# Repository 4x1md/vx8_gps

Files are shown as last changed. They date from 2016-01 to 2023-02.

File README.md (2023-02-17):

# DIY GPS Module for Yaesu VX-8DR/VX-8DE Handheld Transceiver
GPS module for Yaesu VX-8DR/DE handheld transceivers with ublox NEO-6M chip and Arduino Nano by Dmitry Melnichansky 4Z7DTF (~~4X5DM since June 2016~~ 4X1MD since July 24, 2017).

## Overview

When I was buying my Yaesu VX-8DE, I knew that I wasn't going to buy the original Yaesu FGPS2 module. There is very little APRS coverage in Israel and APRS in general seemed quite useless to me. The unreasonably high price of the original module didn't make me want to try it either.

After receiving far APRS stations during a strong tropo over the Mediterranean I thought it would be nice to transmit some data. I started investigating how GPS transmits data and discovered the NMEA protocol I had never encountered before. My first source of information was the article [Reverse Engineering the Yaesu VX-8DR GPS Interface](http://lingnik.com/2013/02/09/reverse-engineering-yaesu-vx-8dr-gps-interface.html) by Taylor J Meek KG7BBG.

I started from writing a Python program which was sending NMEA sentences to the transceiver. After some research I discovered the required message format and wrote a program which drew flowers on APRS map.

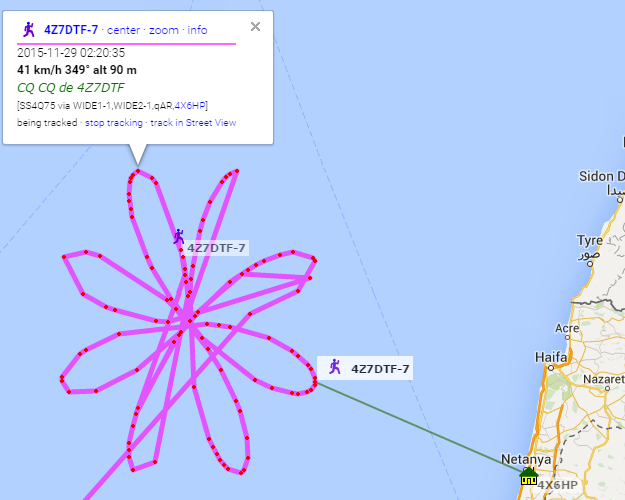
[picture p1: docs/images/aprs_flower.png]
APRS flower


Later, [David Fannin's project](https://github.com/dfannin/arduino-vx8r-gps) inspired me to build my own GPS module. Thanks to his project I found out the ublox NEO-6M chip and a simple search on AliExpress showed that a ready module can be puchased for $10-20.

I wrote my own software which isn't based on David Fannin's code. I started it as Arduino project but after finding out that the standard Arduino Serial library doesn't support interrupt driven writing and reading I decided to write it in pure C. After small changes the C code can be compiled in Arduino environment. The Arduino code is located in [/arduino/vx8_gps_16mhz folder](https://github.com/4x5dm/vx8_gps/blob/master/arduino/vx8_gps_16mhz) of this repository.

I tried to document this project as much as possible and I hope it will be interesting and useful for other radio amateurs.

## Yaesu VX-8DR/DE and NMEA protocol
The NMEA protocol is implemented in the VX-8 in a non-standard way. There are two main issues with it: serial port parameters and NMEA sentence format. There is also a data validation issue which is very interesting but less important in this case.

### Port parameters: baud rate and logic levels
The original Yaesu FGPS2 module transmits at 9600 bps instead of the standard 4800 bps and uses 3.3V logic level instead of the standard 5V. This isn't a big issue because there are GPS modules which can be configured to transmit at 9600 bps and logic levels can be converted. The GY-GPS6MV2 module came already pre-configured to 9600 bps rate. The ublox NEO-6M chip used in this module has maximum supply voltage of 3.6V. As we see there are no electrical compatibility issues at all.
### NMEA sentence format: field lengths
VX-8 requires all the fields of the NMEA sentence to be padded to the maximum possible number of symbols while regular NMEA standart allows fields to be empty. It means that if there is no GPS fix, typical GGA message will have the following form:
```
$GPGGA,074222.000,,,,,0,00,99.9,,,,,,0000*6E
```
The radio won't be able to process this message and we'll see gibberish on the display. A correct sentence for this transceiver should have the following format:
```
$GPGGA,200124.000,0000.0000,N,00000.0000,E,0,00,00.0,00000.0,M,0000.0,M,000.0,0000*46
```
Sending a sentence with empty fields will result in gibberish on the GPS screen of VX-8. Here is what we'll get.

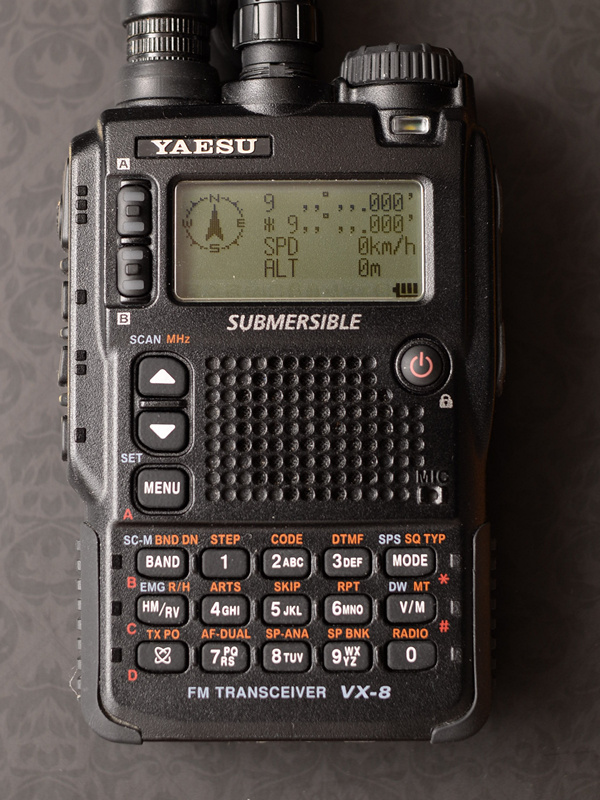
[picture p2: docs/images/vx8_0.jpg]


Allthough the sentence accords with the standard, the transceiver isn't able to process it correctly.

Actually setting number of sybols in each field is what all this project is about! If the second issue didn't exist we could connect the ublox NEO-6M chip based module directly to the transceiver.

### NMEA data validation
Here the things get even more interesting. Yaesu VX-8 does no validation on the NMEA data. When I say no validation, I mean **no validation at all**! Let's look at the following NMEA sentence.
```
$GPGGA,999999.000,73DE.0000,!,Z7DTF.NOPQ,4,1,04
```
The time in the first field is invalid, the latitude and longitude fields have letters instead of numbers, the North/South and East/West fields have invalid characters as well. The checksum is missing. Should it be thrown away by the receiving device? Yes, sure! But let's see how VX-8 will respond!

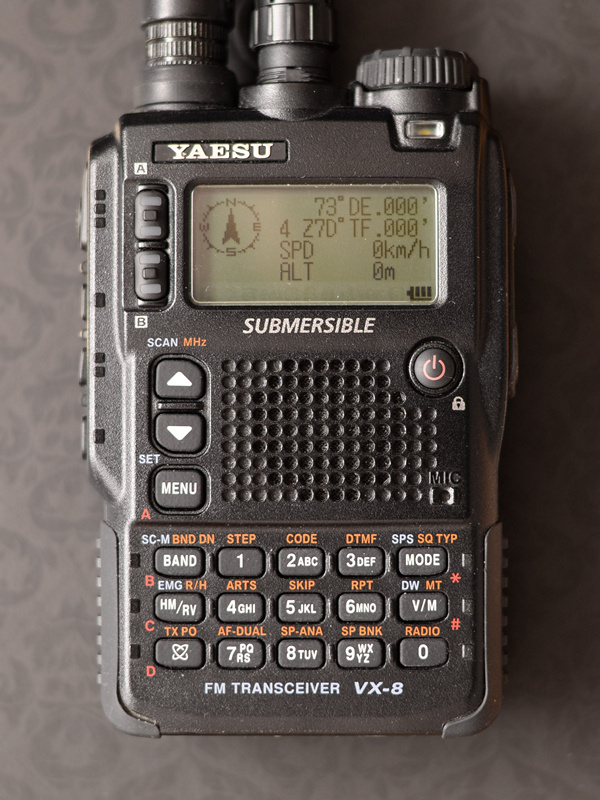
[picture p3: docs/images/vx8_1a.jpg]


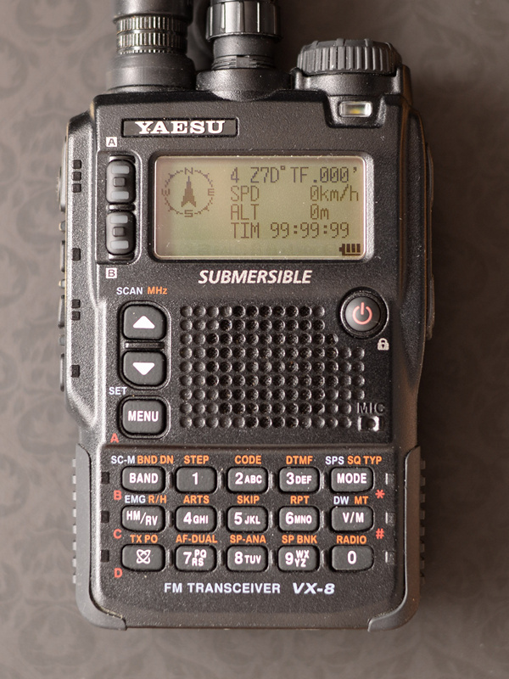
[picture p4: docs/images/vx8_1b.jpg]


Have you ever thought about writing some text on the display of your VX-8? Or maybe about setting the time to 89:91:75? Now you know how to do it!

Let's try one more example where there will be no numbers in latitude and longitude fields.
```
$GPGGA,999999.000,ello.ABCD,H,itHub.ABCD,G,1,04
```
And the output is:

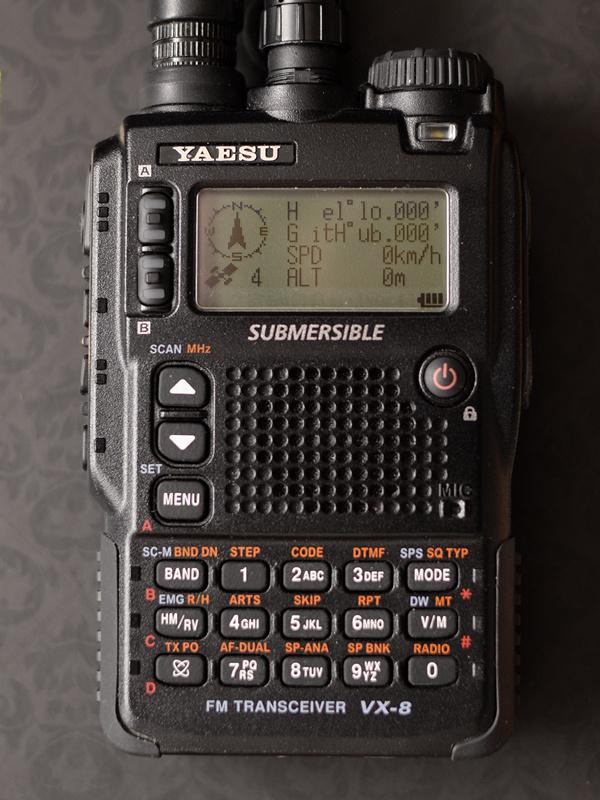
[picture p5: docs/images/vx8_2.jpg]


Note that last two fields of our so called NMEA sentence mean that there was a valid GPS fix and that it was acquired from 4 satellites. This is exactly what we see on the display: satellites icon with number 4 under it.  This is enough for the transceiver to enable APRS beacon transmission. If you press the internet (TX PO) key these coordinates will be transmitted. Obviously, APRS site will mark such packet as invalid.

When I told you that there is no data validation I really meant no validation at all! You don't even have to add checksum as it will be completely ignored by the radio.

If you want to try it your self you'll need a standard programming cable (original or one from AliExpress) and a terminal program. I used [PuTTY](http://www.putty.org/). Open a new session, choose the correct serial port, set it to 9600 8N1 and you are ready to go. Right mouse click in the terminal window pastes the message from the clipboard. After pasting your message press CTRL+M and then CTRL+J. It will send the CR and LF (ASCII 13 and 10) symbols which mark the end of NMEA sentence.

## Hardware

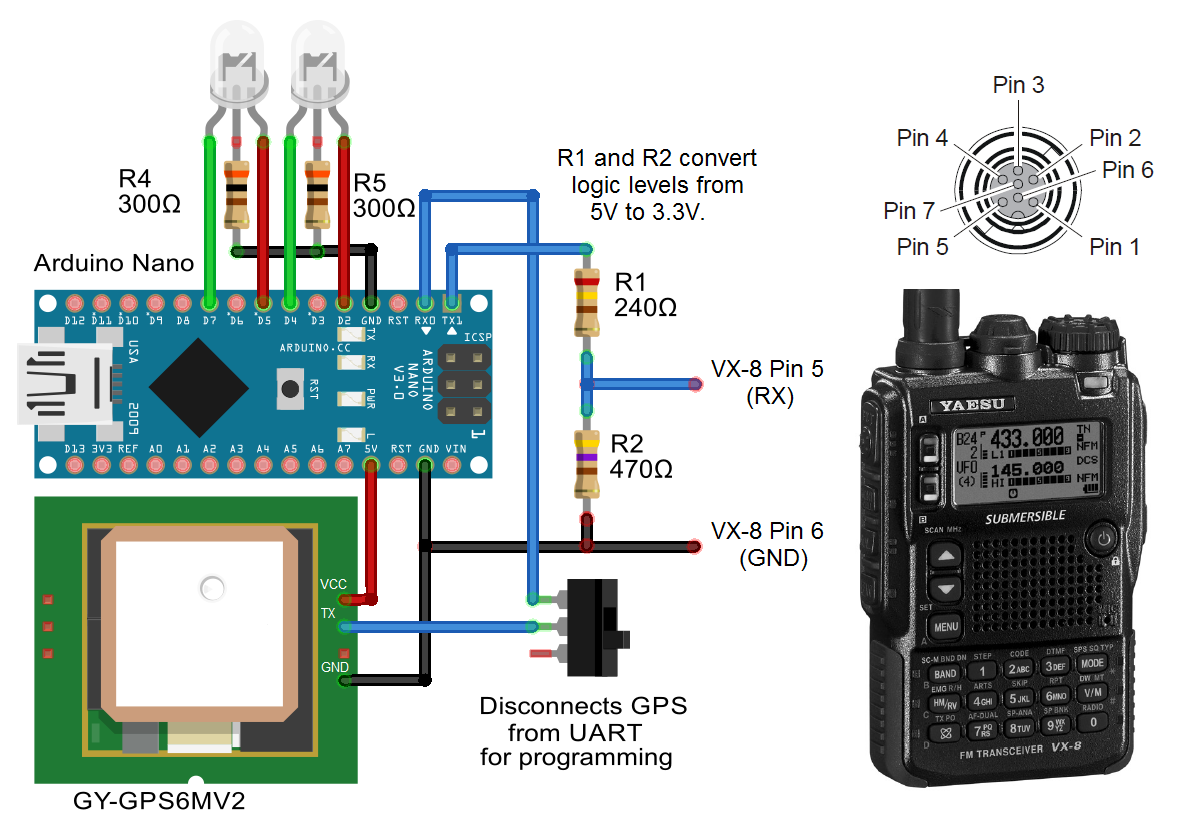
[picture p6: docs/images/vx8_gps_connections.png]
Schematic


The hardware is quite simple. GY-GPS6MV2 GPS module transmits its data to the Arduino which does necessary processing and sends it to the transceiver. Allthough the communication between the original Yaesu FGPS2 module and the radio is bi-directional, in my project I decided to make it unidirectional from GPS to radio. Not only is the bi-directional communication useless in this case but also requires one more serial port. This configuration uses only one serial port to communicate with both devices.

Important! The serial port on the Arduino board is also used for programming the device. Leaving the GPS connected to the serial RX pin will cause a conflict and make uploading the firmware impossible. That's why there is a switch which disconnects GPS output from serial input.

On the contrary, using USB serial when the transceiver is connected not only is possible but also is recommended for debugging purposes. You can use any terminal program to monitor Arduino's output even when the radio is connected.

Voltage divider formed by 240 Ohm and 470 Ohm resistors converts the logic levels from 5V used by Arduino to 3.3V required by the transceiver. Two two-color LEDs are used for indication. The left one blinks red if a GGA message was rejected and green if it was sent to the radio. The right one does the same for RMC messages.

All the setup is very similar to [David Fannin's GPS project](https://github.com/dfannin/arduino-vx8r-gps). Main difference is that his project implements bi-directional communication using software serial port emulation for the second port.

The GY-GPS6MV2 GPS recevier and the Arduino Nano clone were both purchases on AliExpress for less than $15.

## Software

To be completed...

## Development history

### First protoype: Arduino Nano and u-blox NEO-6M

The first version was built with readily available modules on a prototype PCB.

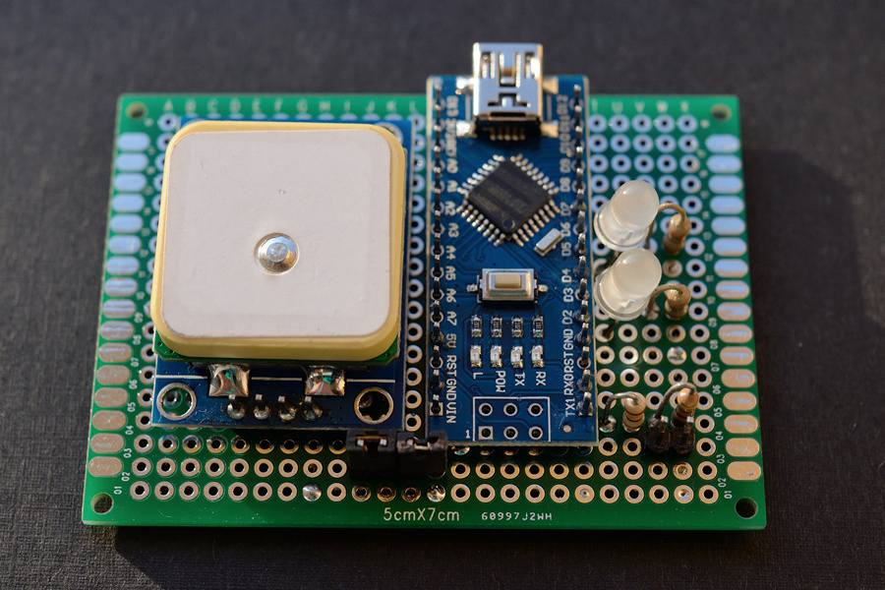
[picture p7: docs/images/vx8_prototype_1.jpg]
Prototype


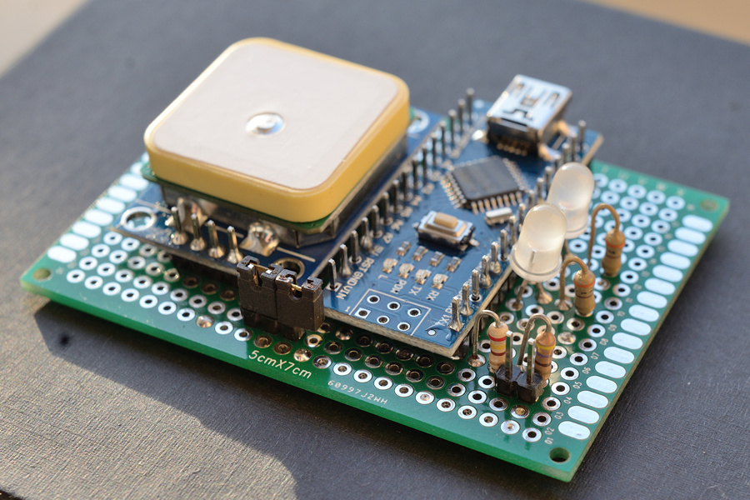
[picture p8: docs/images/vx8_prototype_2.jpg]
Prototype


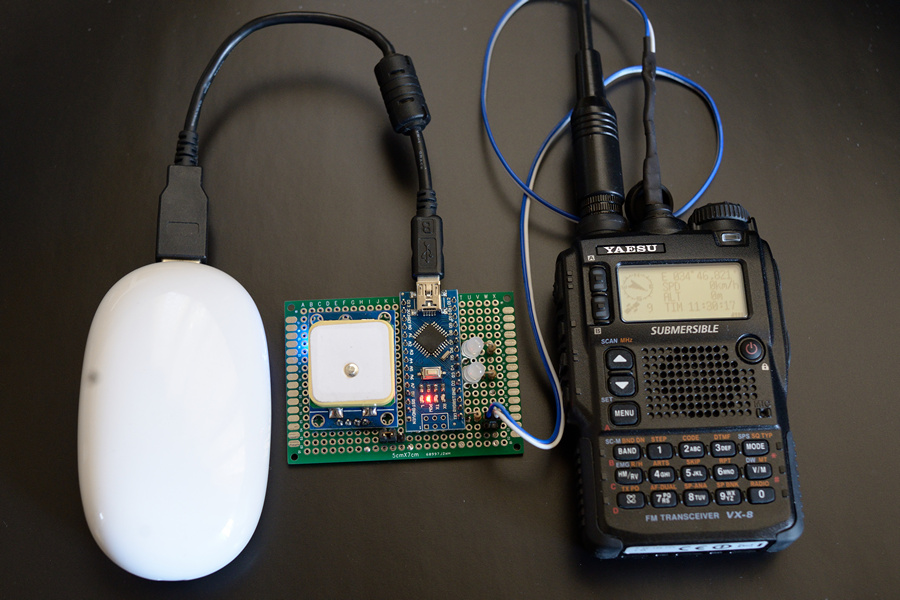
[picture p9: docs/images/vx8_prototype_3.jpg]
Prototype


### PCB v1.0

The first prototype was built on a dedicated PCB with a standalone ATmega328P-20PU microcontroller in 28 pin DIP package. The PCB was produced at home.

Refer to [prototype_v1.0.md](https://github.com/4x5dm/vx8_gps/blob/master/docs/prototype_v1.0.md) for details.

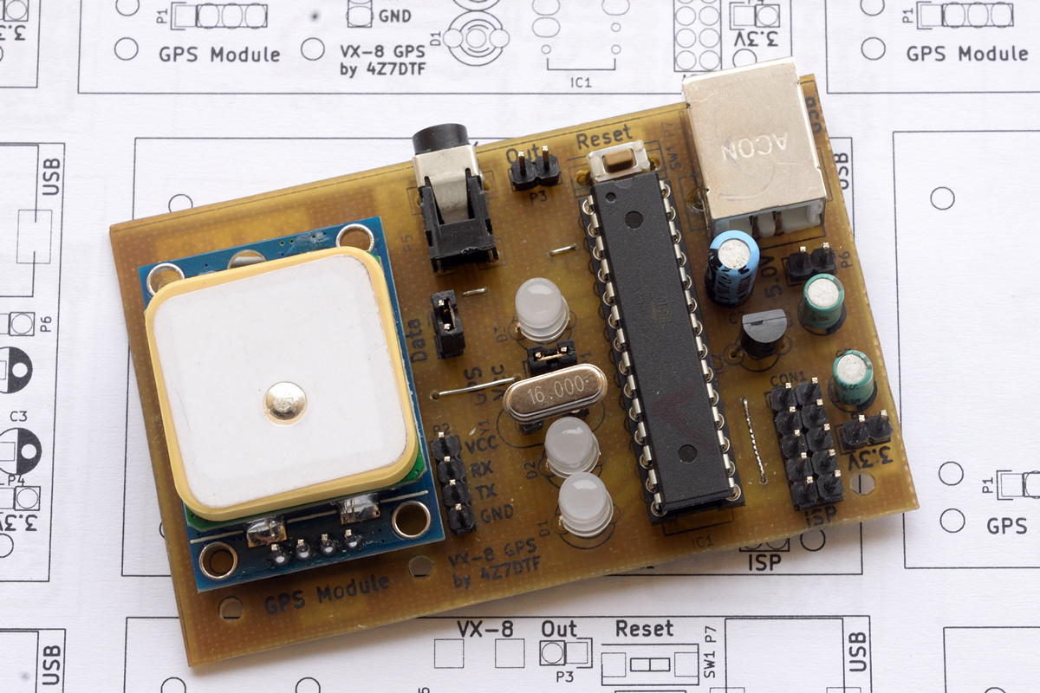
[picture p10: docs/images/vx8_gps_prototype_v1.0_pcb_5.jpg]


### PCB v2.0

This version has a USB-to-UART IC which allows the GPS to be used as a programming cable. It was designed as a two-side PCB with SMD parts. Allthough I developed the schematics and the PCB, this version was never built.

The circuit diagram of this version can be found [here](https://raw.githubusercontent.com/4x5dm/vx8_gps/master/docs/images/vx8_gps_prototype_v2.0_schematic.png). Design files are located [here](https://github.com/4x1md/vx8_gps/tree/master/pcbs/vx8_gps_prototype_v2.0).

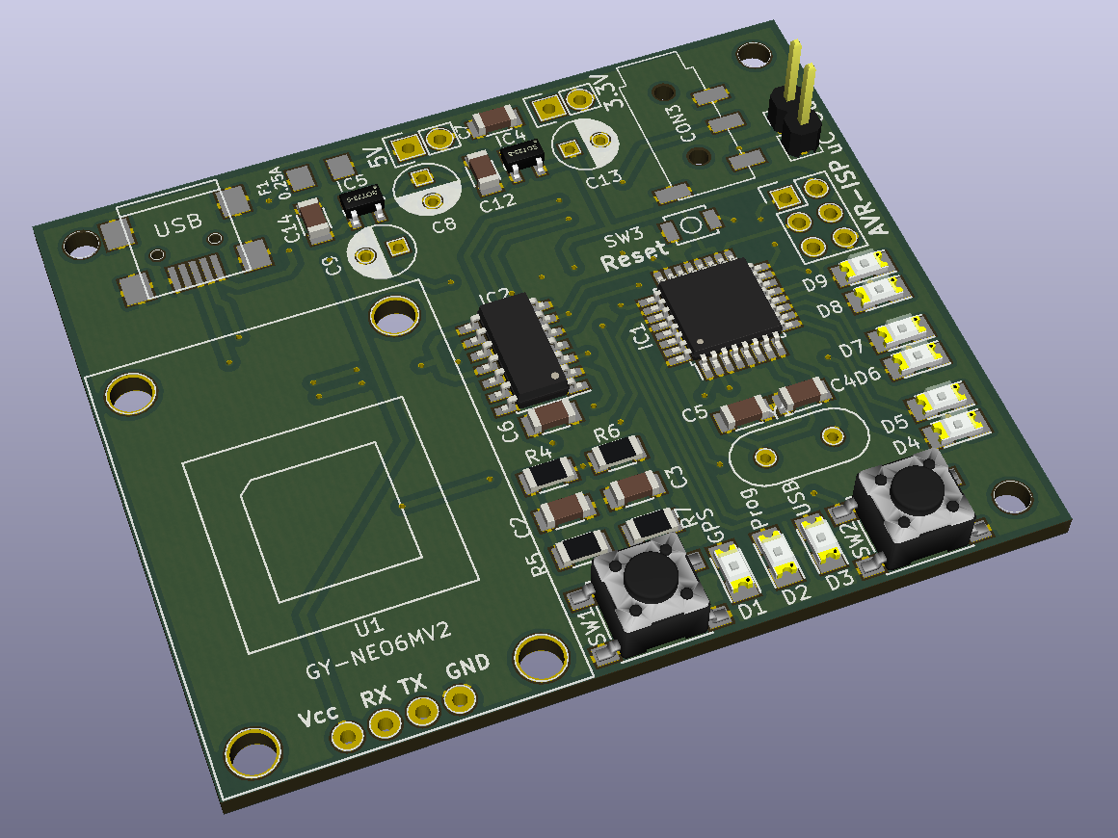
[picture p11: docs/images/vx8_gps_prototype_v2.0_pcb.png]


### PCB v3.0

This version was built on a two-layer PCB. Most parts including ATmega328P microcontroller and the GPS module are SMD. The size of this PCB is 43.5x43.5mm and it was designed to fit a small plastic enclosure box.

Refer to [prototype_v3.0.md](https://github.com/4x5dm/vx8_gps/blob/master/docs/prototype_v3.0.md) for details.

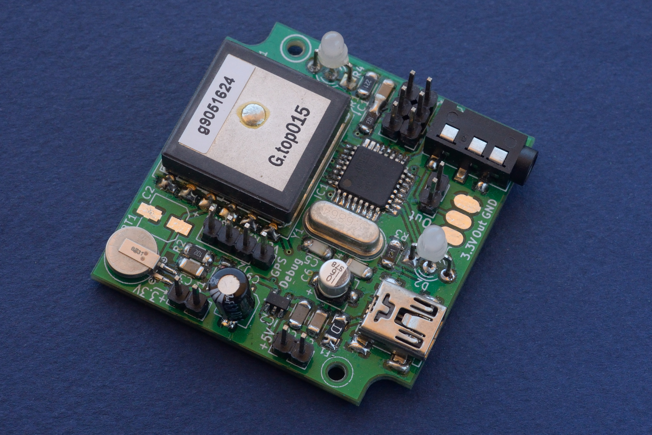
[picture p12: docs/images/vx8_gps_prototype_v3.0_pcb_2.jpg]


## Field tests

The unit was tested in trains. Videos from the tests are available.

1. [Test 1: Herzliya station](http://www.youtube.com/watch?v=POHEborbWdw)
2. [Test 2: Kiryat Gat station](https://www.youtube.com/watch?v=_s_EKdAwrpI)

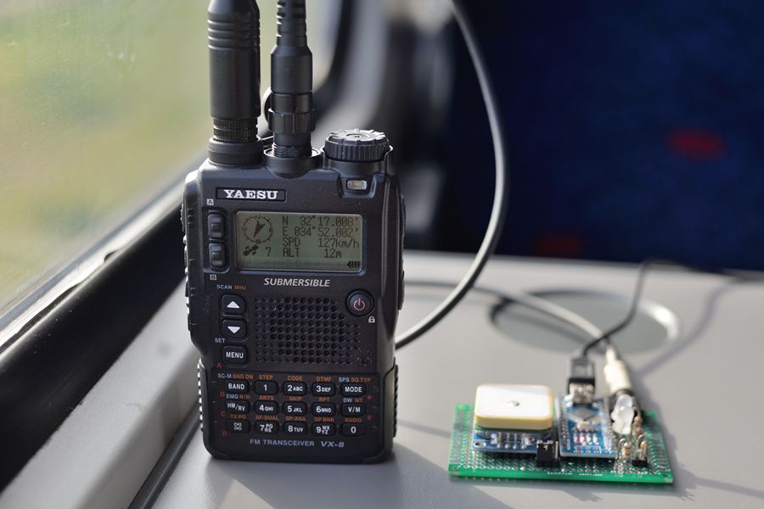
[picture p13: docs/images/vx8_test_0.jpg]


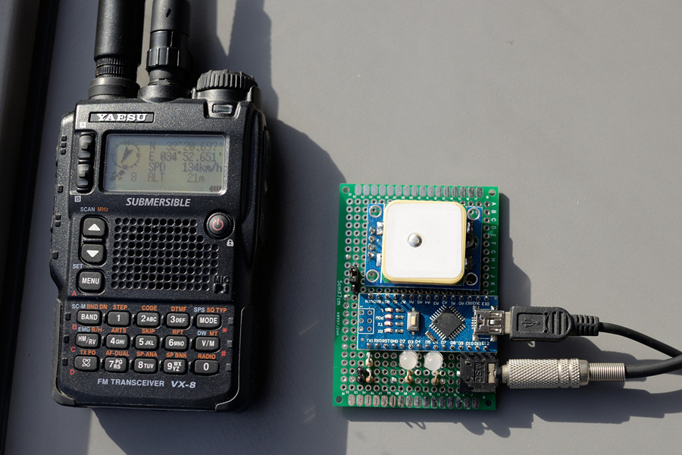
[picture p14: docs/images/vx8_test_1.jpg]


## Plans for future development

1. [x] ~~Running all the system at 3.3V.~~ See [prototype_v1.0.md](https://github.com/4x5dm/vx8_gps/blob/master/docs/prototype_v1.0.md) for details.
2. [x] ~~Reducing the microcontroller speed to 8MHz or even lower.~~ See [Release v1.0](https://github.com/4x5dm/vx8_gps/releases/tag/v1.0) ([commit 9e8273a](https://github.com/4x5dm/vx8_gps/commit/9e8273abed9b53197791b6e432649a282e6ca909)) .
3. [ ] Adding a rechargeable battery and making the device USB chargeable.
4. [x] ~~Building the project on a PCB instead of using ready modules.~~
5. [x] ~~Assembling the device in one enclosure box.~~
6. [ ] Making the module compatible with Nikon DSLRs.

Optional/questionable features:

1. [ ] USB serial chip to use the device as a programming cable.
2. [ ] microSD card slot and keeping logs of the tracks.
3. [ ] LCD display for displaying current GPS data.

## Links
1. [Reverse Engineering the Yaesu VX-8DR GPS Interface](http://lingnik.com/2013/02/09/reverse-engineering-yaesu-vx-8dr-gps-interface.html)
2. [FGPS2 data samples (VX-8R Yahoo Group)](https://groups.yahoo.com/neo/groups/VX_8R/conversations/topics/7719)
3. [David Fannin's Yaesu VX-8R Handheld Transmitter-compatible GPS](https://github.com/dfannin/arduino-vx8r-gps)
4. [NMEA to Yaesu VX-8 by G7UHN](http://alloutput.com/amateur-radio/nmea-to-yaesu-vx-8/)
5. [VX-8DR and GPS by VK3YY](https://vk3yy.wordpress.com/2015/07/24/vx-8dr-and-gps/)
6. [GPS - NMEA sentence information](http://aprs.gids.nl/nmea/)
7. [MTK NMEA checksum calculator](http://www.hhhh.org/wiml/proj/nmeaxor.html)
8. [avr-libc 2.0.0: <avr/interrupt.h>: Interrupts](http://www.nongnu.org/avr-libc/user-manual/group__avr__interrupts.html)

## Questions? Suggestions?
You are more than welcome to contact me with any questions, suggestions or propositions regarding this project. You can:

1. Visit [my QRZ.COM page](https://www.qrz.com/db/4X5DM)
2. Visit [my Facebook profile](https://www.facebook.com/Dima.Meln)
3. Write me an email to iosaaris =at= gmail dot com

## How to Support or Say Thanks

If you like this project, or found here some useful information and want to say thanks, or encourage me to do more, you can buy me a coffee!



"Buy Me A Coffee" (https://www.buymeacoffee.com/4x1md)

You can aslo make a donation with PayPal:



---

**73 de 4X1MD ex 4X5DM ex 4Z7DTF**

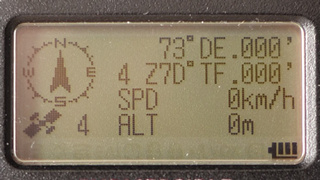
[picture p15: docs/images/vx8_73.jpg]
73's


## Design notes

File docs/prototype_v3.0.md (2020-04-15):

# DIY GPS module for Yaesu VX-8DR/VX-8DE Version 3.0

## Overview

This version of the GPS was developed in order to reduce its size and to assemble it in a small plastic enclosure. It is built on a two-layer PCB.

Both schematics and the PCB were developed in KiCAD software. Source files are available in [pcbs/vx8_gps_prototype_v3.0](https://github.com/4x1md/vx8_gps/blob/master/pcbs/vx8_gps_prototype_v3.0) of this repository.

## Schematics

This version uses a G.top015 surface-mounted GPS module based on MTK3333 chipset. It supports both GPS and GLONASS. The module transmits GPS data at 9600 bps. It is very simple to use and doesn't require any software configuration. It uses 3.3V logic levels which match those required by VX-8DR. In order to keep the internal RTC running when the main power is turned off, an external battery can be used. Without it the module will perform a lengthy cold start every time it is powered-on because previous satellite information is not retained and needs to be reacquired. MS621FE backup battery is used in this project.

The microcontroller is ATmega328P like in the previous versions. This version uses the TQFP-32 package.

The circuit is powered from an external 5V source. The power is supplied through a Micro-USB connector. It makes possible to power the GPS from a portable power bank with a USB port. The GPS module and the microcontroller need 3.3V to function. This voltage is supplied by MIC5205-3.3BM5 fixed output linear regulator.

All the passive parts are 1206 SMD for easy soldering. The only through-hole parts are crystal, LEDs and terminal headers.

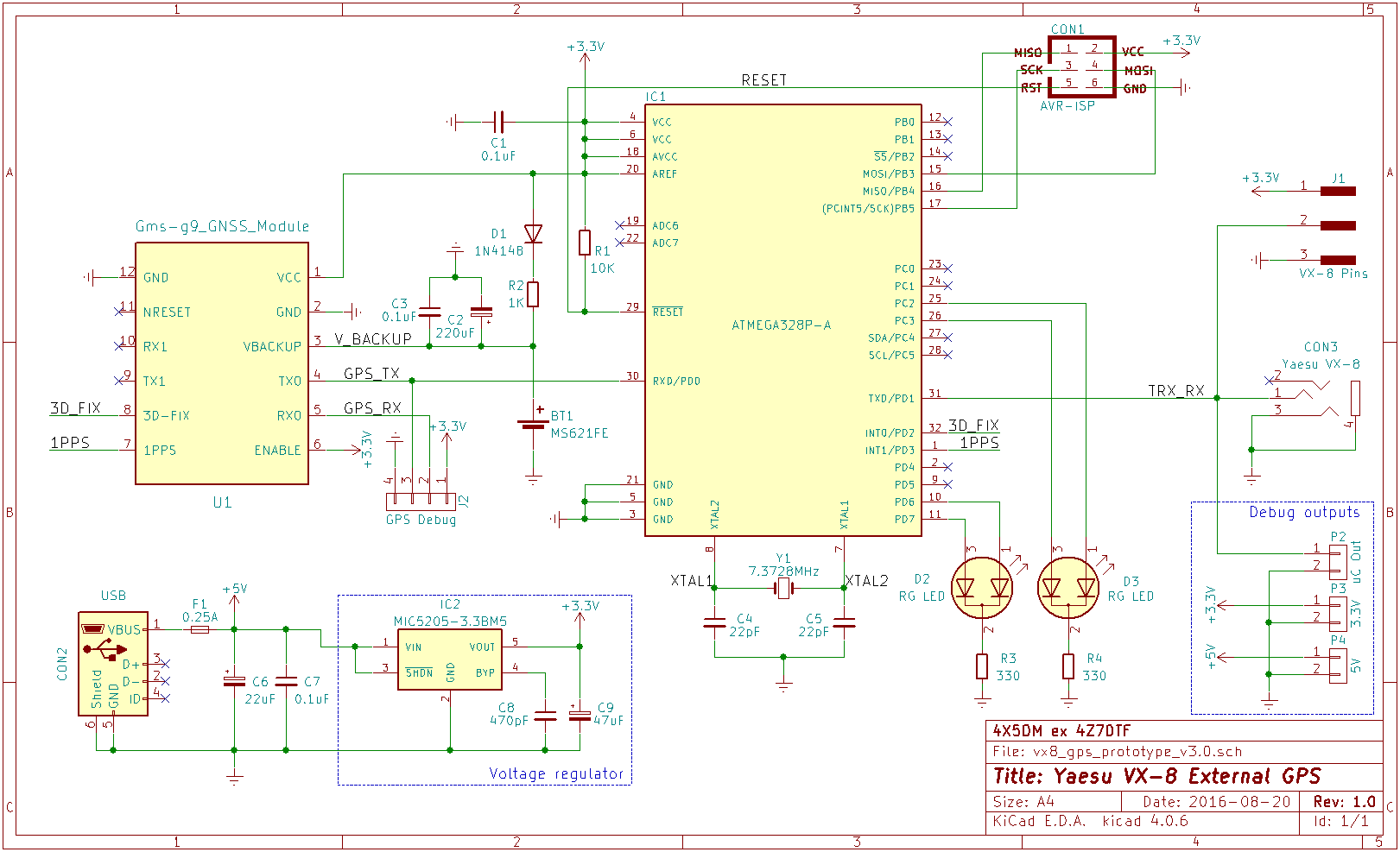
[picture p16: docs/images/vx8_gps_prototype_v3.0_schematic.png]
Schematic


## Mechanics

One of the requirements of this GPS version was an enclosure box. I chose 51x51x15mm plastic box which is small, strong and can be bought cheap on eBay and AliExpress.

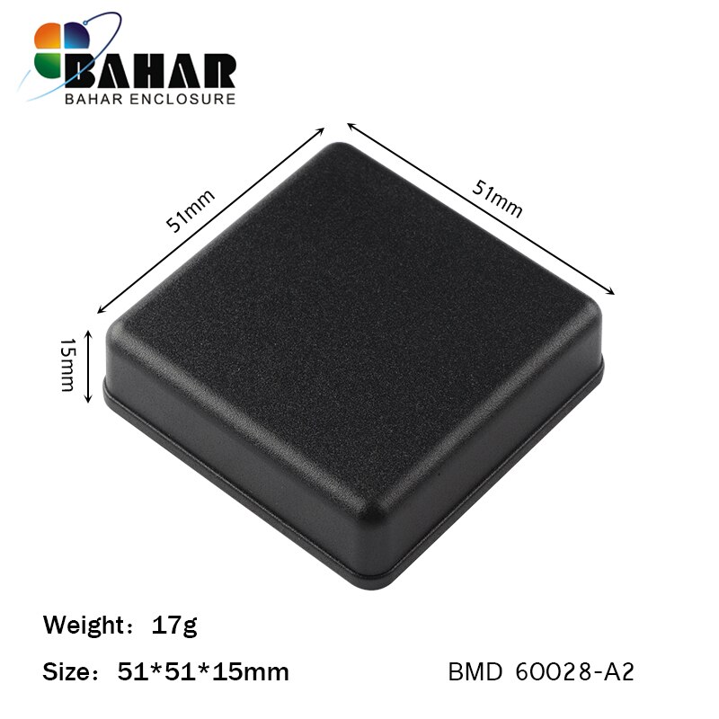
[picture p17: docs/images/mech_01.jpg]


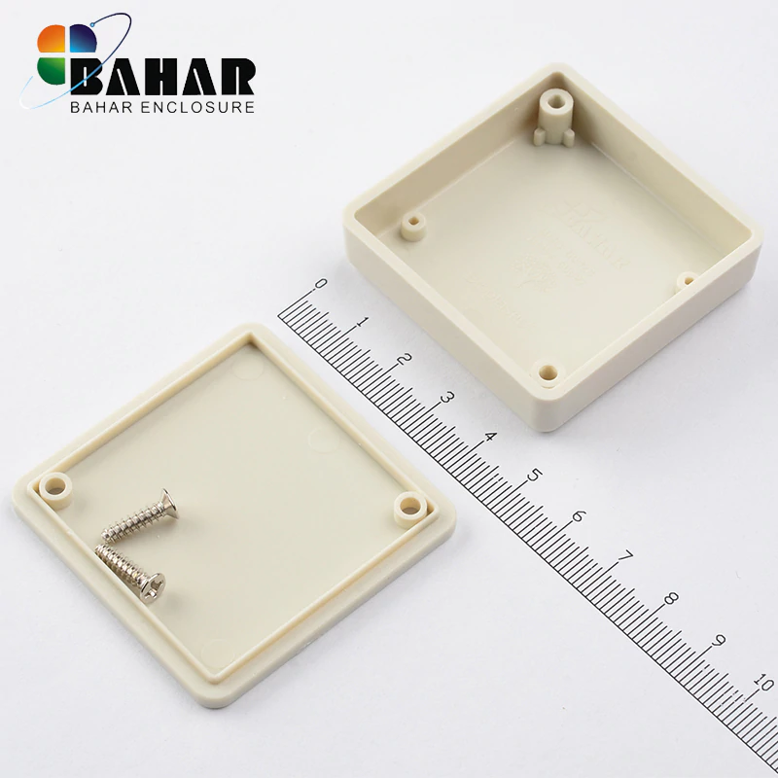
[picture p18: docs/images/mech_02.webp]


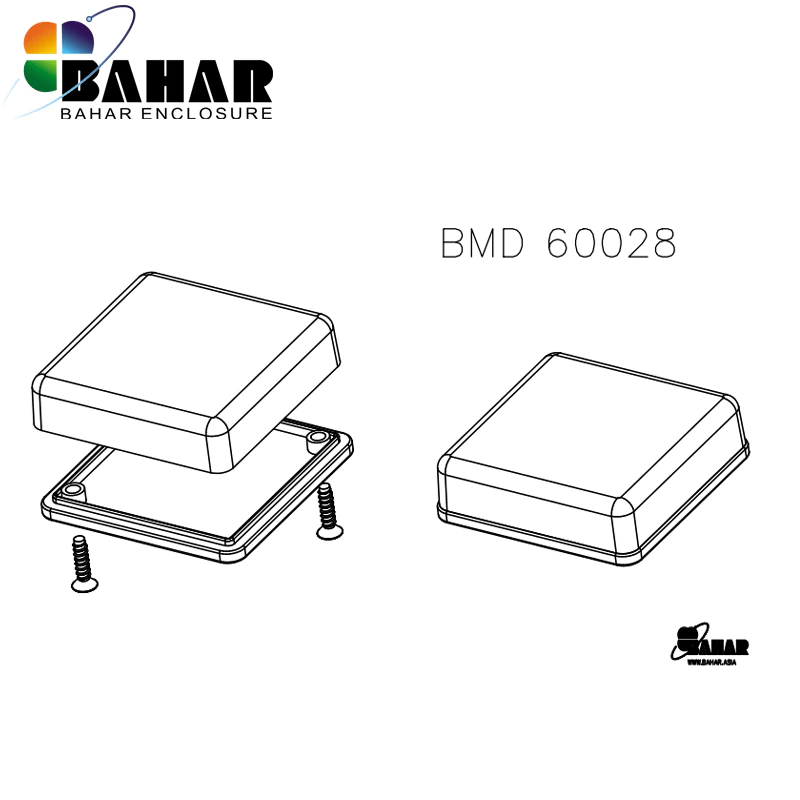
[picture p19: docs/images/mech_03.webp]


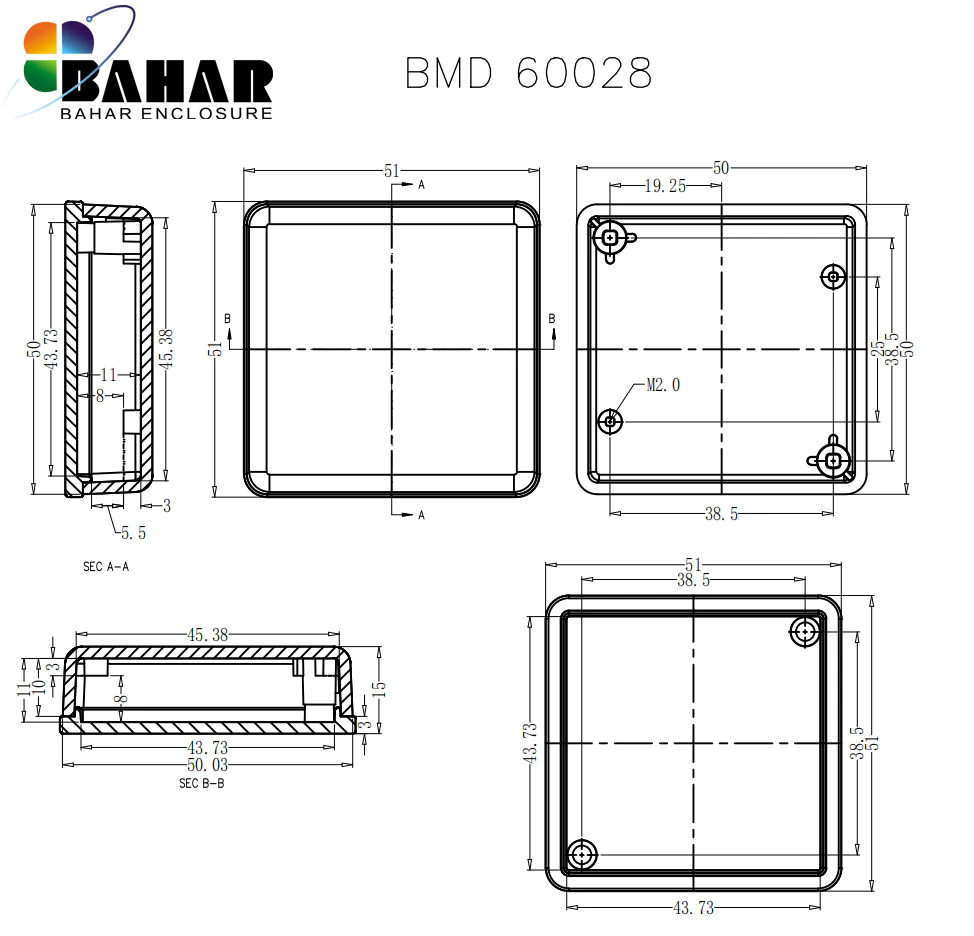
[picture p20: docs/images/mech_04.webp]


## PCB

The PCB is a two-layer board. Its size is 43.5x43.5mm based on manual measurement of the enclosure box.

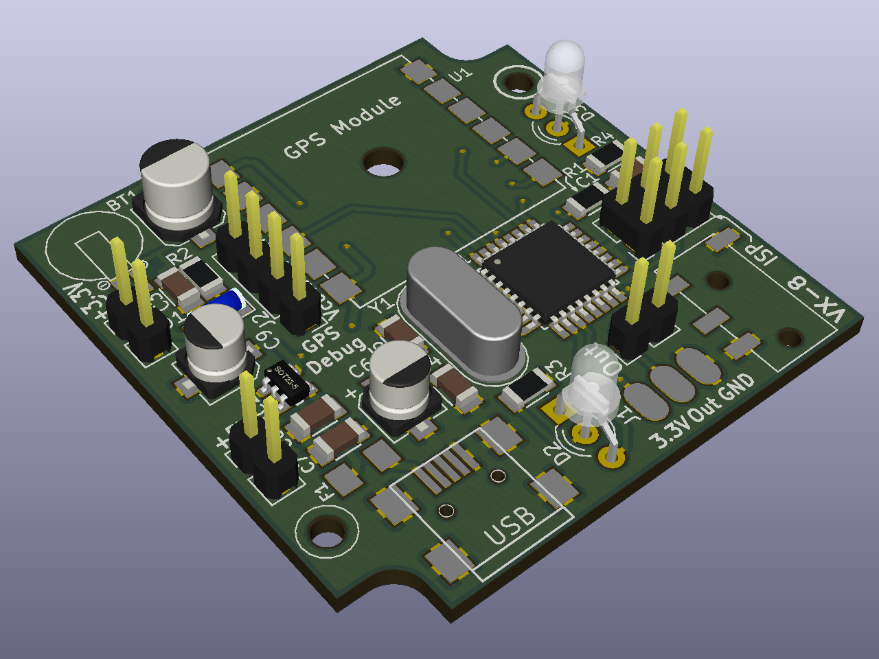
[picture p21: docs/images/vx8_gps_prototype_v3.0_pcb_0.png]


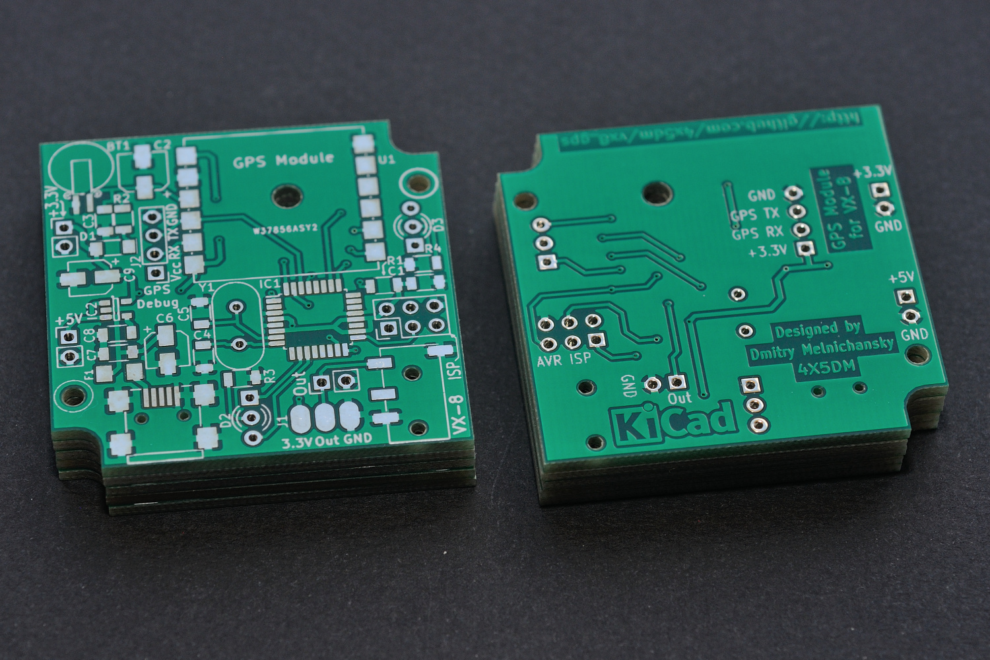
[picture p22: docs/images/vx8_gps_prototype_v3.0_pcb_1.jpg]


## Photos

PCB

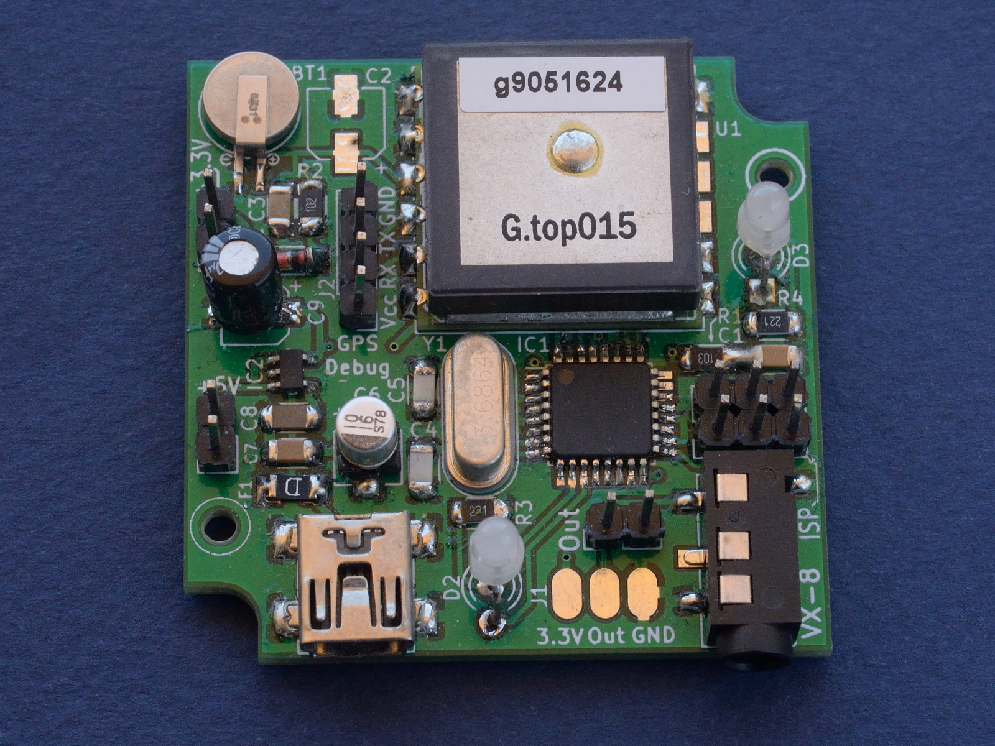
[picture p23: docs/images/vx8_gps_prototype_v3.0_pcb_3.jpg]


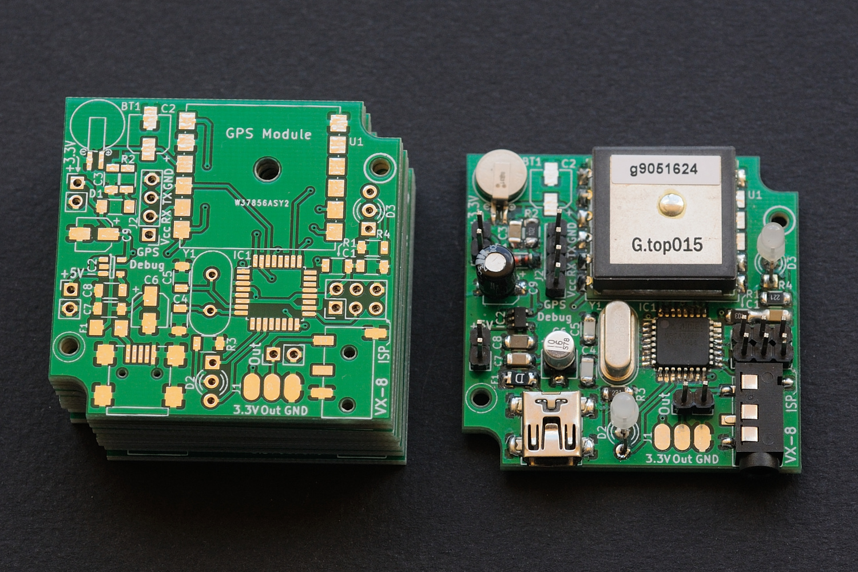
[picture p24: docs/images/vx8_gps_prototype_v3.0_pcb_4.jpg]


## Field Tests

The new module was tested in Israel and abroad and I'm satisficed with its performance.

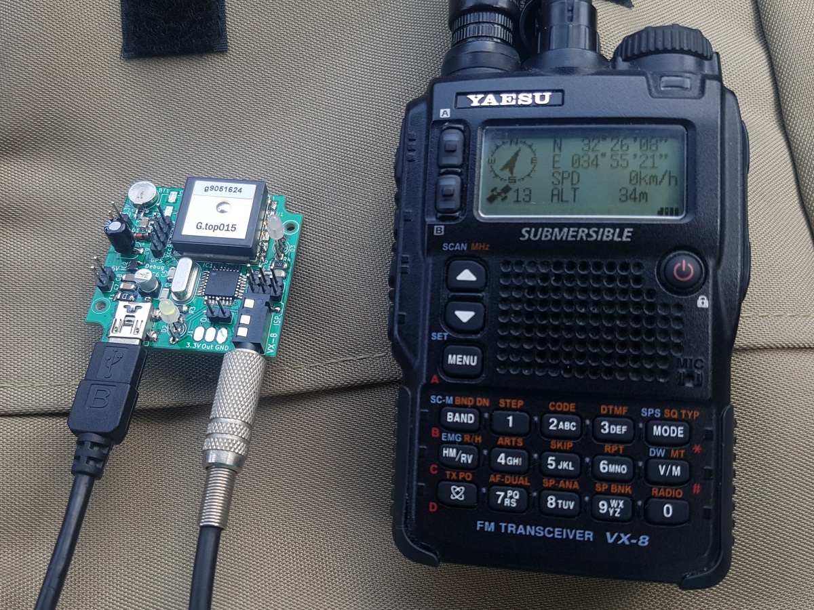
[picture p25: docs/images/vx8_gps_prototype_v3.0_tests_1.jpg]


73 from 4X1MD

73's

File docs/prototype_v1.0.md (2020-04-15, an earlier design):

# DIY GPS module for Yaesu VX-8DR/VX-8DE Prototype v1.0

## Overview

One of the aims of the future development of this project is lowering the clock frequency as much as possible. Arduino boards lack the possibility to freely replace the crystal which in this case is necessary. The prototype v1.0 serves as development board providing wider flexibility than Arduino boards. It is built on a dedicated PCB with a standalone ATmega328P-20PU microcontroller in 28 pin DIP package.

Both schematics and the PCB were developed in KiCAD software. Source files are available in [pcbs/vx8_gps_prototype_v1.0](https://github.com/4x1md/vx8_gps/blob/master/pcbs/vx8_gps_prototype_v1.0) of this repository.

## Schematics

The schematics are quite simple. The prototype consists of a microcontroller, an LM317 based voltage regulator and some LEDs for indication purposes.

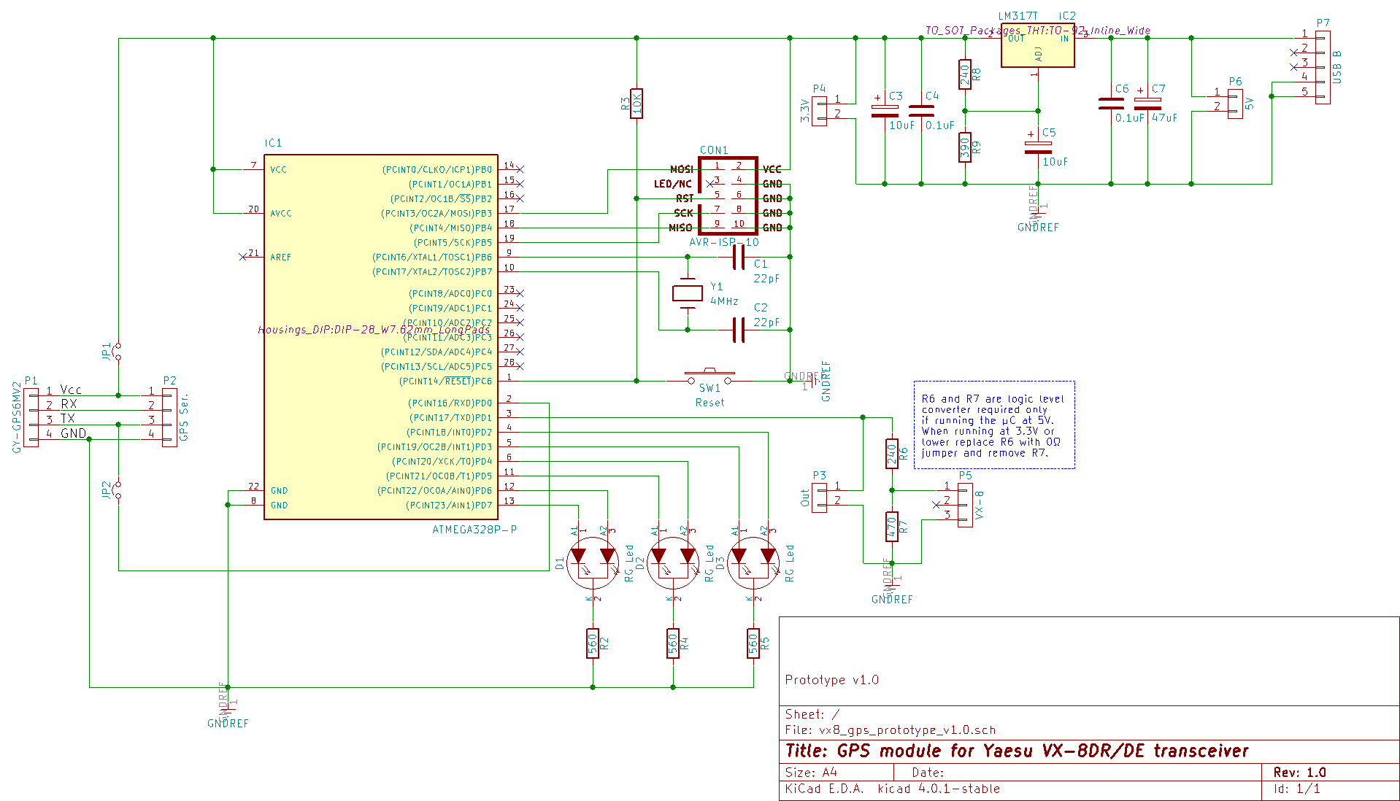
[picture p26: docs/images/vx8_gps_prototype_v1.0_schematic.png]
Schematic


## PCB

The PCB is designed as two layer board where front layer tracks of the real board are replaced with wire jumpers. It uses some 1206 form factor SMD components.

The board was produced at home using Toner Transfer Method.

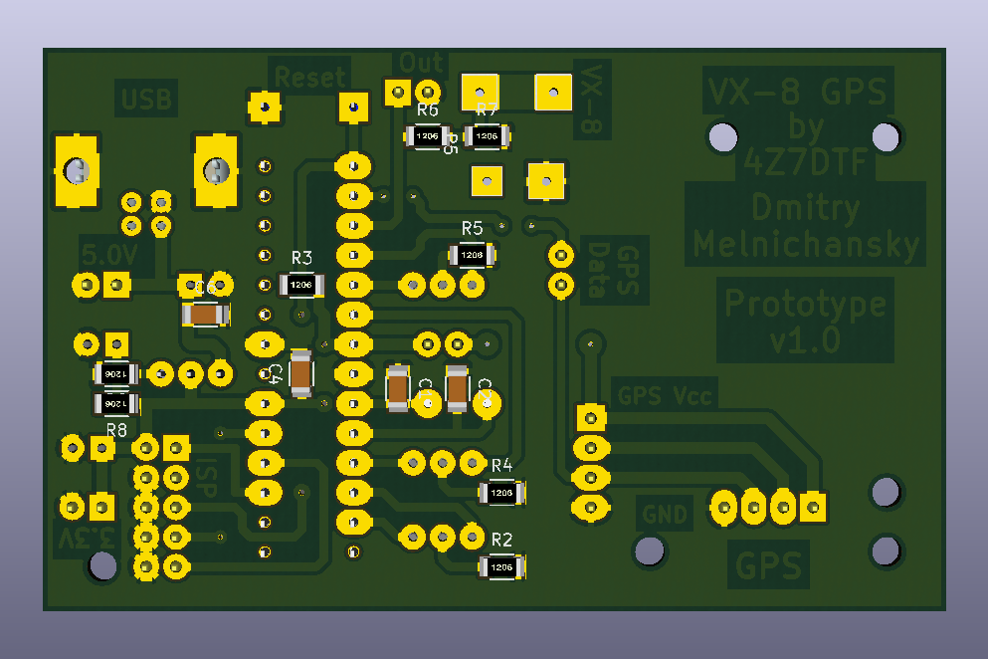
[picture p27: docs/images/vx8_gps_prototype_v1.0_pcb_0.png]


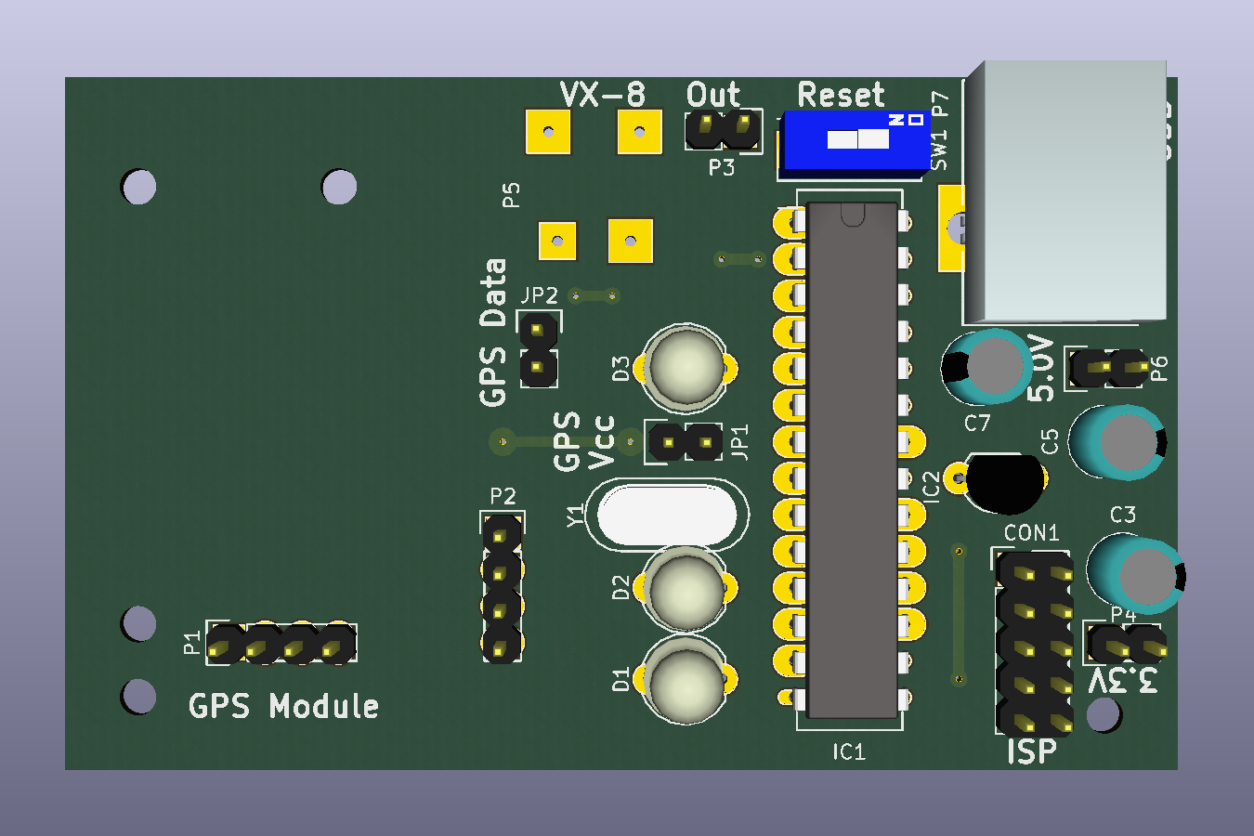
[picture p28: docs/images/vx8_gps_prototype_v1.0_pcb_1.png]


## Photos

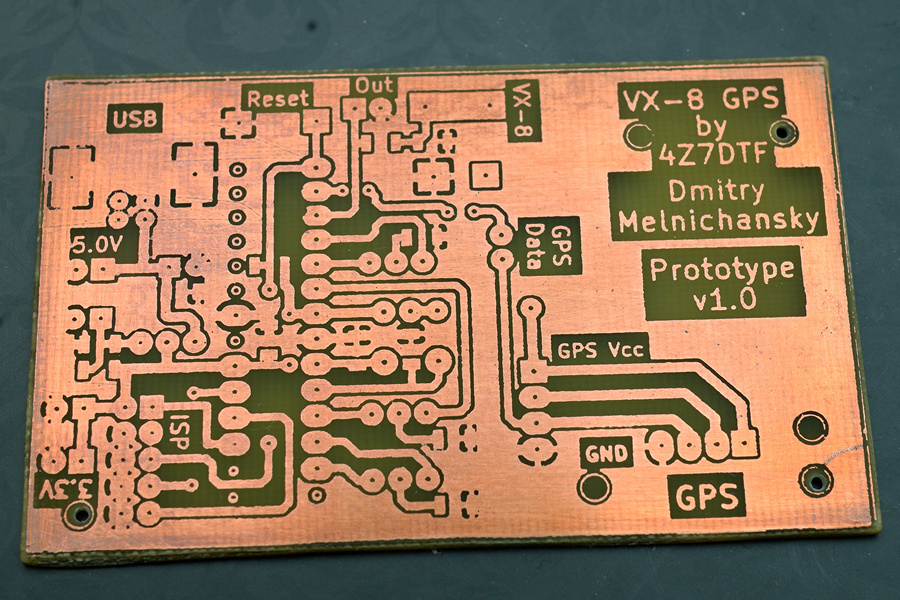
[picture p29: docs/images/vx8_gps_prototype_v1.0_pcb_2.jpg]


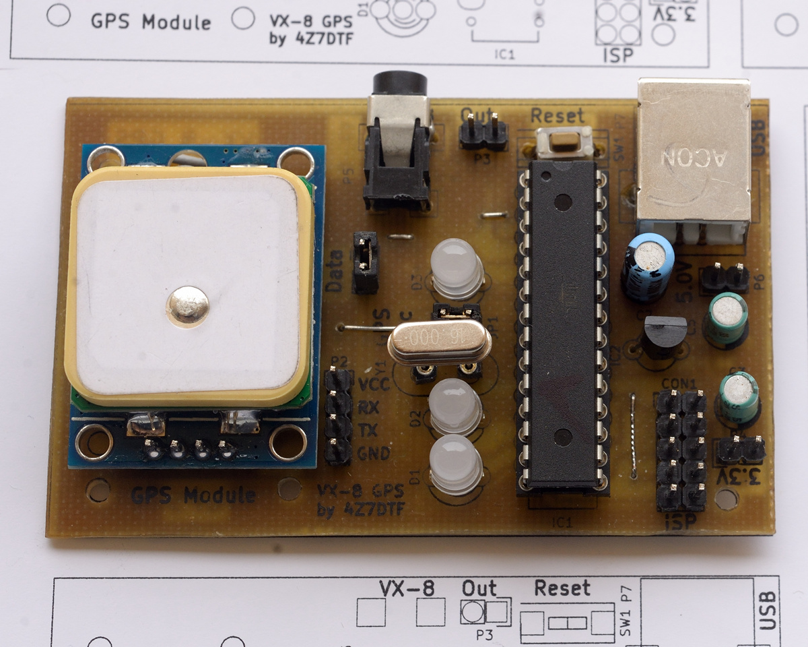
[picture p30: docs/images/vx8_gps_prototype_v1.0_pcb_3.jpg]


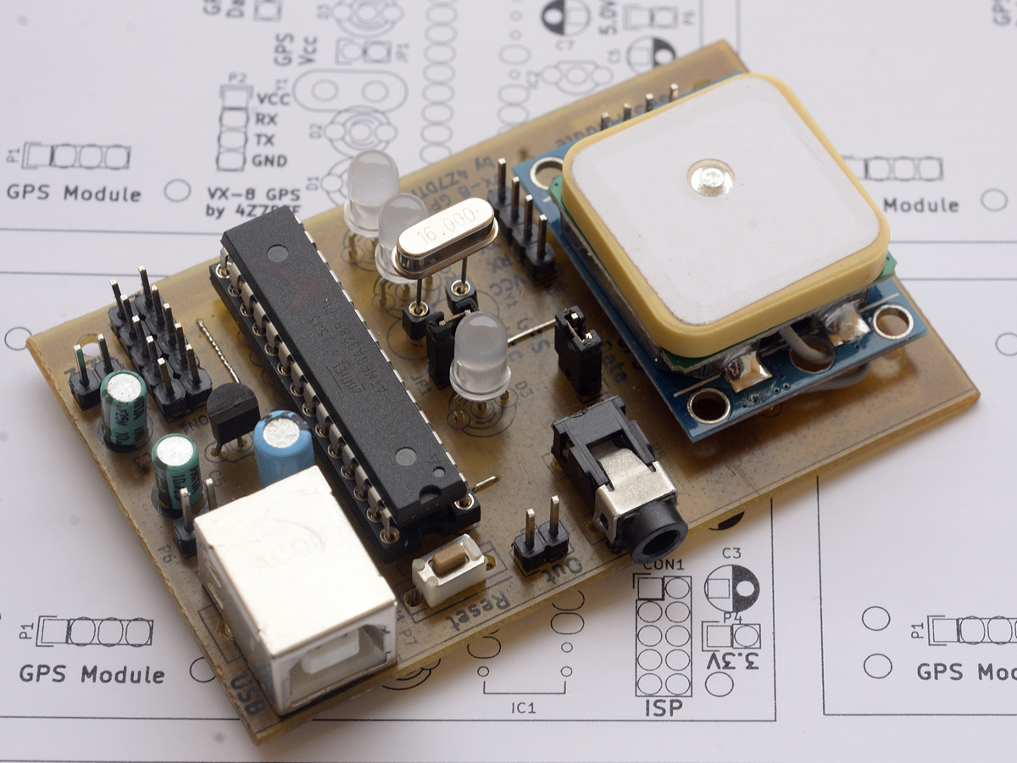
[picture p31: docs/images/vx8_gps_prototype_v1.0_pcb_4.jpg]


PCB

## Links

1. [Cheap and Easy Toner Transfer for PCB Making](http://www.instructables.com/id/Cheap-and-Easy-Toner-Transfer-for-PCB-Making/)
2. [Easy, Consistent & Cheap Toner Transfer Method for Single & Double Sided PCBs](http://www.instructables.com/id/Easy-Consistent-Cheap-Toner-Transfer-Method-for-Si/)

73's

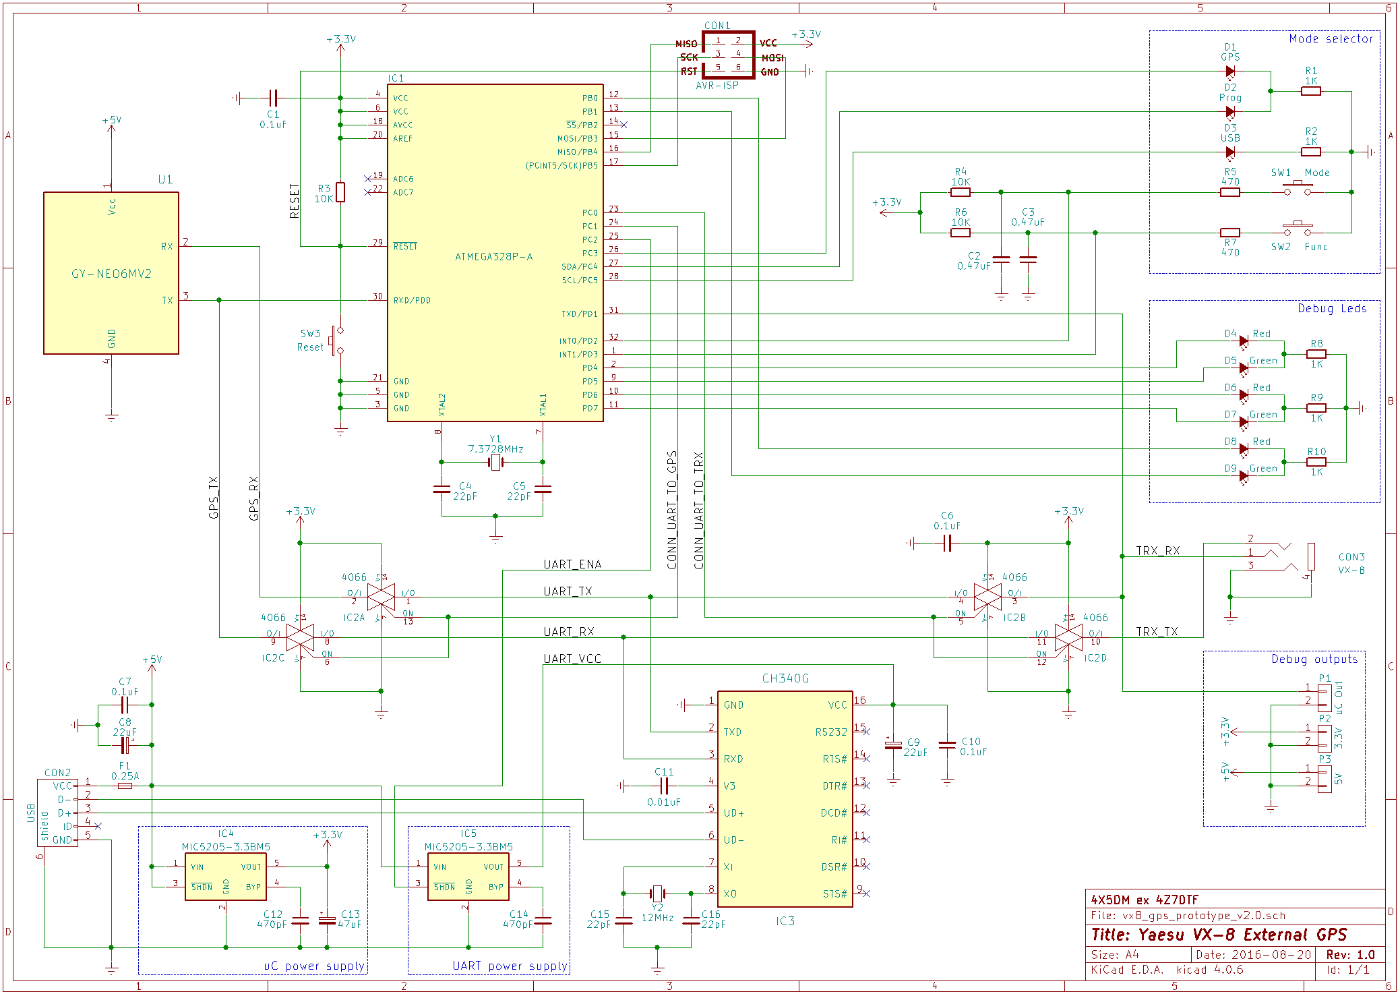
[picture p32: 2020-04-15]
docs/images/vx8_gps_prototype_v2.0_schematic.png

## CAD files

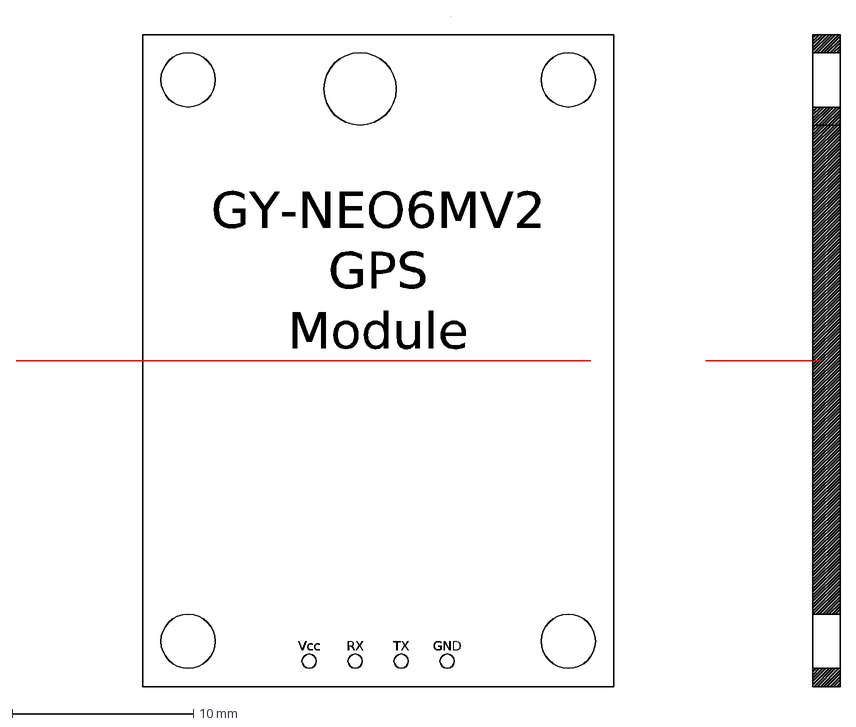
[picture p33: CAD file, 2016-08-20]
docs/GY-NEO6MV2.dxf
GY-NEO6MV2 GPS Module
GND
Vcc
TX
RX

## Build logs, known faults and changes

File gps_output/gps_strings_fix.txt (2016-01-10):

u-blox NEO-6M output when fix was acquired
==========================================

$GPZDA,125347.000,26,12,2015,,*51
$GPGGA,142449.000,3226.0583,N,03454.9160,E,1,03,8.1,82.1,M,18.2,M,,0000*6B
$GPGSA,A,2,02,06,30,,,,,,,,,,8.2,8.1,1.0*36
$GPGSV,3,1,10,02,15,294,31,03,20,146,,05,01,319,,06,26,253,28*70
$GPGSV,3,2,10,07,71,271,22,09,63,013,,16,18,044,,23,43,071,*7C
$GPGSV,3,3,10,28,01,191,,30,40,240,19*73
$GPGLL,3226.0583,N,03454.9160,E,142449.000,A,A*54
$GPZDA,142449.000,26,12,2015,,*59
$GPRMC,142450.000,A,3226.0581,N,03454.9164,E,0.26,,261215,,,A*74
$GPVTG,,T,,M,0.26,N,0.5,K,A*12
$GPGGA,142450.000,3226.0581,N,03454.9164,E,1,04,8.1,82.1,M,18.2,M,,0000*62
$GPGSA,A,2,02,23,06,30,,,,,,,,,8.2,8.1,1.0*37
$GPGSV,3,1,10,02,15,294,31,03,20,146,,05,01,319,,06,26,253,28*70
$GPGSV,3,2,10,07,71,271,21,09,63,013,,16,18,044,,23,43,071,16*78
$GPGSV,3,3,10,28,01,191,,30,40,240,19*73
$GPGLL,3226.0581,N,03454.9164,E,142450.000,A,A*5A
$GPZDA,142450.000,26,12,2015,,*51
$GPRMC,142451.000,A,3226.0580,N,03454.9168,E,0.14,,261215,,,A*79
$GPVTG,,T,,M,0.14,N,0.3,K,A*15
$GPGGA,142451.000,3226.0580,N,03454.9168,E,1,04,8.1,82.1,M,18.2,M,,0000*6E
$GPGSA,A,2,02,23,06,30,,,,,,,,,8.2,8.1,1.0*37
$GPGSV,3,1,10,02,15,294,31,03,20,146,,05,01,319,,06,26,253,28*70
$GPGSV,3,2,10,07,71,271,22,09,63,013,,16,18,044,,23,43,071,15*78
$GPGSV,3,3,10,28,01,191,,30,40,240,19*73
$GPGLL,3226.0580,N,03454.9168,E,142451.000,A,A*56
$GPZDA,142451.000,26,12,2015,,*50
$GPRMC,142452.000,A,3226.0579,N,03454.9175,E,0.87,,261215,,,A*7A
$GPVTG,,T,,M,0.87,N,1.6,K,A*1B
$GPGGA,142452.000,3226.0579,N,03454.9175,E,1,04,8.1,82.1,M,18.2,M,,0000*67
$GPGSA,A,2,02,23,06,30,,,,,,,,,8.2,8.1,1.0*37
$GPGSV,3,1,10,02,15,294,31,03,20,146,,05,01,319,,06,26,253,27*7F
$GPGSV,3,2,10,07,71,271,22,09,63,013,,16,18,044,,23,43,071,15*78
$GPGSV,3,3,10,28,01,191,,30,40,240,19*73
$GPGLL,3226.0579,N,03454.9175,E,142452.000,A,A*5F
$GPZDA,142452.000,26,12,2015,,*53
$GPRMC,142453.000,A,3226.0578,N,03454.9167,E,1.50,,261215,,,A*72
$GPVTG,,T,,M,1.50,N,2.8,K,A*1D
$GPGGA,142453.000,3226.0578,N,03454.9167,E,1,04,8.1,82.1,M,18.2,M,,0000*64
$GPGSA,A,2,02,23,06,30,,,,,,,,,8.2,8.1,1.0*37
$GPGSV,3,1,10,02,15,294,31,03,20,146,,05,01,319,,06,26,253,27*7F
$GPGSV,3,2,10,07,71,271,21,09,63,013,,16,18,044,,23,43,071,11*7F
$GPGSV,3,3,10,28,01,191,,30,40,240,18*72
$GPGLL,3226.0578,N,03454.9167,E,142453.000,A,A*5C
$GPZDA,142453.000,26,12,2015,,*52
$GPRMC,142454.000,A,3226.0578,N,03454.9177,E,0.66,,261215,,,A*70
$GPVTG,,T,,M,0.66,N,1.2,K,A*10
$GPGGA,142454.000,3226.0578,N,03454.9177,E,1,05,8.1,82.1,M,18.2,M,,0000*63
$GPGSA,A,2,02,23,06,09,30,,,,,,,,8.2,8.1,1.0*3E
$GPGSV,3,1,10,02,15,294,31,03,20,146,,05,01,319,,06,26,253,27*7F
$GPGSV,3,2,10,07,71,271,22,09,63,013,13,16,18,044,,23,43,071,10*7F
$GPGSV,3,3,10,28,01,191,,30,40,240,18*72
$GPGLL,3226.0578,N,03454.9177,E,142454.000,A,A*5A
$GPZDA,142454.000,26,12,2015,,*55
$GPRMC,142455.000,A,3226.0505,N,03454.8651,E,1.65,,261215,,,A*7B
$GPVTG,,T,,M,1.65,N,3.1,K,A*13
$GPGGA,142455.000,3226.0505,N,03454.8651,E,1,04,5.0,71.7,M,18.2,M,,0000*6D
$GPGSA,A,3,02,23,06,30,,,,,,,,,11.6,5.0,10.4*32
$GPGSV,3,1,10,02,15,294,31,03,20,146,,05,01,319,,06,26,253,27*7F
$GPGSV,3,2,10,07,71,271,22,09,63,013,,16,18,044,,23,43,071,10*7D
$GPGSV,3,3,10,28,01,191,,30,40,240,18*72
$GPGLL,3226.0505,N,03454.8651,E,142455.000,A,A*53
$GPZDA,142455.000,26,12,2015,,*54
$GPRMC,142456.000,A,3226.0483,N,03454.8515,E,1.19,,261215,,,A*7F
$GPVTG,,T,,M,1.19,N,2.2,K,A*1A
$GPGGA,142456.000,3226.0483,N,03454.8515,E,1,04,5.0,72.4,M,18.2,M,,0000*62
$GPGSA,A,3,02,23,06,30,,,,,,,,,11.6,5.0,10.4*32
$GPGSV,3,1,10,02,15,294,31,03,20,146,,05,01,319,,06,26,253,27*7F
$GPGSV,3,2,10,07,71,271,23,09,63,013,,16,18,044,,23,43,071,10*7C
$GPGSV,3,3,10,28,01,191,,30,40,240,19*73
$GPGLL,3226.0483,N,03454.8515,E,142456.000,A,A*5C
$GPZDA,142456.000,26,12,2015,,*57
$GPRMC,142457.000,A,3226.0481,N,03454.8472,E,1.47,,261215,,,A*77
$GPVTG,,T,,M,1.47,N,2.7,K,A*14
$GPGGA,142457.000,3226.0481,N,03454.8472,E,1,05,5.0,74.8,M,18.2,M,,0000*6A
$GPGSA,A,3,02,23,06,09,30,,,,,,,,11.5,5.0,10.4*38
$GPGSV,3,1,10,02,15,294,31,03,20,146,,05,01,319,,06,26,253,27*7F
$GPGSV,3,2,10,07,71,271,23,09,63,013,13,16,18,044,,23,43,071,07*78
$GPGSV,3,3,10,28,01,191,,30,40,240,20*79
$GPGLL,3226.0481,N,03454.8472,E,142457.000,A,A*5F
$GPZDA,142457.000,26,12,2015,,*56
$GPRMC,142458.000,A,3226.0482,N,03454.8441,E,1.78,,261215,,,A*77
$GPVTG,,T,,M,1.78,N,3.3,K,A*1D
$GPGGA,142458.000,3226.0482,N,03454.8441,E,1,05,5.0,77.7,M,18.2,M,,0000*6A
$GPGSA,A,3,02,23,06,09,30,,,,,,,,11.5,5.0,10.4*38
$GPGSV,3,1,10,02,15,294,30,03,20,146,,05,01,319,,06,26,253,28*71
$GPGSV,3,2,10,07,71,271,23,09,63,013,12,16,18,044,,23,43,071,07*79
$GPGSV,3,3,10,28,01,191,,30,40,240,20*79
$GPGLL,3226.0482,N,03454.8441,E,142458.000,A,A*53
$GPZDA,142458.000,26,12,2015,,*59
$GPRMC,142459.000,A,3226.0484,N,03454.8410,E,2.34,,261215,,,A*7F
$GPVTG,,T,,M,2.34,N,4.3,K,A*11
$GPGGA,142459.000,3226.0484,N,03454.8410,E,1,05,5.0,80.5,M,18.2,M,,0000*63
$GPGSA,A,3,02,23,06,09,30,,,,,,,,11.5,5.0,10.4*38
$GPGSV,3,1,10,02,15,294,30,03,20,146,,05,01,319,,06,26,253,27*7E
$GPGSV,3,2,10,07,71,271,23,09,63,013,10,16,18,044,,23,43,071,07*7B
$GPGSV,3,3,10,28,01,191,,30,40,240,20*79
$GPGLL,3226.0484,N,03454.8410,E,142459.000,A,A*50
$GPZDA,142459.000,26,12,2015,,*58
$GPRMC,142500.000,A,3226.0485,N,03454.8383,E,2.80,,261215,,,A*71
$GPVTG,,T,,M,2.80,N,5.2,K,A*1E
$GPGGA,142500.000,3226.0485,N,03454.8383,E,1,05,5.0,81.6,M,18.2,M,,0000*60
$GPGSA,A,3,02,23,06,09,30,,,,,,,,11.5,5.0,10.3*3F
$GPGSV,3,1,10,02,15,294,31,03,20,146,,05,01,319,,06,26,253,27*7F
$GPGSV,3,2,10,07,71,271,22,09,63,013,10,16,18,044,,23,43,071,07*7A
$GPGSV,3,3,10,28,01,191,,30,40,240,20*79
$GPGLL,3226.0485,N,03454.8383,E,142500.000,A,A*51
$GPZDA,142500.000,26,12,2015,,*55
$GPRMC,142501.000,A,3226.0487,N,03454.8356,E,2.34,,261215,,,A*75
$GPVTG,,T,,M,2.34,N,4.3,K,A*11
$GPGGA,142501.000,3226.0487,N,03454.8356,E,1,04,4.9,84.2,M,18.2,M,,0000*63
$GPGSA,A,3,02,23,06,30,,,,,,,,,11.5,4.9,10.3*3E
$GPGSV,3,1,10,02,15,294,30,03,20,146,,05,01,319,,06,26,253,27*7E
$GPGSV,3,2,10,07,71,271,22,09,63,013,09,16,18,044,,23,43,071,07*72
$GPGSV,3,3,10,28,01,191,,30,40,240,20*79
$GPGLL,3226.0487,N,03454.8356,E,142501.000,A,A*5A
$GPZDA,142501.000,26,12,2015,,*54
$GPRMC,142502.000,A,3226.0485,N,03454.8323,E,2.55,,261215,,,A*71
$GPVTG,,T,,M,2.55,N,4.7,K,A*12
$GPGGA,142502.000,3226.0485,N,03454.8323,E,1,04,4.9,84.7,M,18.2,M,,0000*65
$GPGSA,A,3,02,23,06,30,,,,,,,,,11.5,4.9,10.3*3E
$GPGSV,3,1,10,02,15,294,30,03,20,146,,05,01,319,,06,26,253,27*7E
$GPGSV,3,2,10,07,71,271,22,09,63,013,,16,18,044,,23,43,071,07*7B
$GPGSV,3,3,10,28,01,191,,30,40,240,21*78
$GPGLL,3226.0485,N,03454.8323,E,142502.000,A,A*59
$GPZDA,142502.000,26,12,2015,,*57
$GPRMC,142503.000,A,3226.0482,N,03454.8288,E,4.14,,261215,,,A*74
$GPVTG,,T,,M,4.14,N,7.7,K,A*12
$GPGGA,142503.000,3226.0482,N,03454.8288,E,1,04,4.9,85.3,M,18.2,M,,0000*66
$GPGSA,A,3,02,23,06,30,,,,,,,,,11.4,4.9,10.3*3F
$GPGSV,3,1,10,02,15,294,31,03,20,146,,05,01,319,,06,26,253,27*7F
$GPGSV,3,2,10,07,71,271,23,09,63,013,,16,18,044,,23,43,071,08*75
$GPGSV,3,3,10,28,01,191,,30,40,240,22*7B
$GPGLL,3226.0482,N,03454.8288,E,142503.000,A,A*5F
$GPZDA,142503.000,26,12,2015,,*56
$GPRMC,142504.000,A,3226.0477,N,03454.8250,E,5.51,269.32,261215,,,A*6E
$GPVTG,269.32,T,,M,5.51,N,10.2,K,A*33
$GPGGA,142504.000,3226.0477,N,03454.8250,E,1,04,4.9,85.1,M,18.2,M,,0000*6C
$GPGSA,A,3,02,23,06,30,,,,,,,,,11.4,4.9,10.3*3F
$GPGSV,3,1,10,02,15,294,31,03,20,146,,05,01,319,,06,26,253,26*7E
$GPGSV,3,2,10,07,71,271,22,09,63,013,,16,18,044,,23,43,071,08*74
$GPGSV,3,3,10,28,01,191,,30,40,240,22*7B
$GPGLL,3226.0477,N,03454.8250,E,142504.000,A,A*57
$GPZDA,142504.000,26,12,2015,,*51
$GPRMC,142505.000,A,3226.0470,N,03454.8211,E,6.14,264.95,261215,,,A*6F
$GPVTG,264.95,T,,M,6.14,N,11.4,K,A*36
$GPGGA,142505.000,3226.0470,N,03454.8211,E,1,04,4.9,87.0,M,18.2,M,,0000*6C
$GPGSA,A,3,02,23,06,30,,,,,,,,,11.4,4.9,10.3*3F
$GPGSV,3,1,10,02,15,294,31,03,20,146,,05,01,319,,06,26,253,26*7E
$GPGSV,3,2,10,07,71,271,22,09,63,013,,16,18,044,,23,43,071,08*74
$GPGSV,3,3,10,28,01,191,,30,40,240,21*78
$GPGLL,3226.0470,N,03454.8211,E,142505.000,A,A*54
$GPZDA,142505.000,26,12,2015,,*50
$GPRMC,142506.000,A,3226.0468,N,03454.8173,E,6.12,265.88,261215,,,A*69
$GPVTG,265.88,T,,M,6.12,N,11.3,K,A*3A
$GPGGA,142506.000,3226.0468,N,03454.8173,E,1,04,4.9,87.0,M,18.2,M,,0000*61
$GPGSA,A,3,02,23,06,30,,,,,,,,,11.4,4.9,10.2*3E
$GPGSV,3,1,10,02,15,294,31,03,20,146,,05,01,319,,06,26,253,27*7F
$GPGSV,3,2,10,07,71,271,21,09,63,013,,16,18,044,,23,43,071,08*77
$GPGSV,3,3,10,28,01,191,,30,40,240,18*72
$GPGLL,3226.0468,N,03454.8173,E,142506.000,A,A*59
$GPZDA,142506.000,26,12,2015,,*53
$GPRMC,142507.000,A,3226.0466,N,03454.8128,E,7.34,266.34,261215,,,A*69
$GPVTG,266.34,T,,M,7.34,N,13.6,K,A*3C
$GPGGA,142507.000,3226.0466,N,03454.8128,E,1,04,4.9,88.0,M,18.2,M,,0000*6F
$GPGSA,A,3,02,23,06,30,,,,,,,,,11.4,4.9,10.2*3E
$GPGSV,3,1,10,02,15,294,30,03,20,146,,05,01,319,,06,26,253,27*7E
$GPGSV,3,2,10,07,71,271,22,09,63,013,,16,18,044,,23,43,071,08*74
$GPGSV,3,3,10,28,01,191,,30,40,240,14*7E
$GPGLL,3226.0466,N,03454.8128,E,142507.000,A,A*58
$GPZDA,142507.000,26,12,2015,,*52
$GPRMC,142508.000,A,3226.0468,N,03454.8090,E,8.08,267.22,261215,,,A*6C
$GPVTG,267.22,T,,M,8.08,N,15.0,K,A*3A
$GPGGA,142508.000,3226.0468,N,03454.8090,E,1,04,4.9,89.5,M,18.2,M,,0000*68
$GPGSA,A,3,02,23,06,30,,,,,,,,,11.3,4.9,10.2*39
$GPGSV,3,1,10,02,15,294,30,03,20,146,,05,01,319,,06,26,253,26*7F
$GPGSV,3,2,10,07,71,271,23,09,63,013,,16,18,044,,23,43,071,08*75
$GPGSV,3,3,10,28,01,191,,30,40,240,16*7C
$GPGLL,3226.0468,N,03454.8090,E,142508.000,A,A*5B
$GPZDA,142508.000,26,12,2015,,*5D
$GPRMC,142509.000,A,3226.0469,N,03454.8054,E,8.35,268.53,261215,,,A*63
$GPVTG,268.53,T,,M,8.35,N,15.5,K,A*38
$GPGGA,142509.000,3226.0469,N,03454.8054,E,1,04,4.9,91.8,M,18.2,M,,0000*64

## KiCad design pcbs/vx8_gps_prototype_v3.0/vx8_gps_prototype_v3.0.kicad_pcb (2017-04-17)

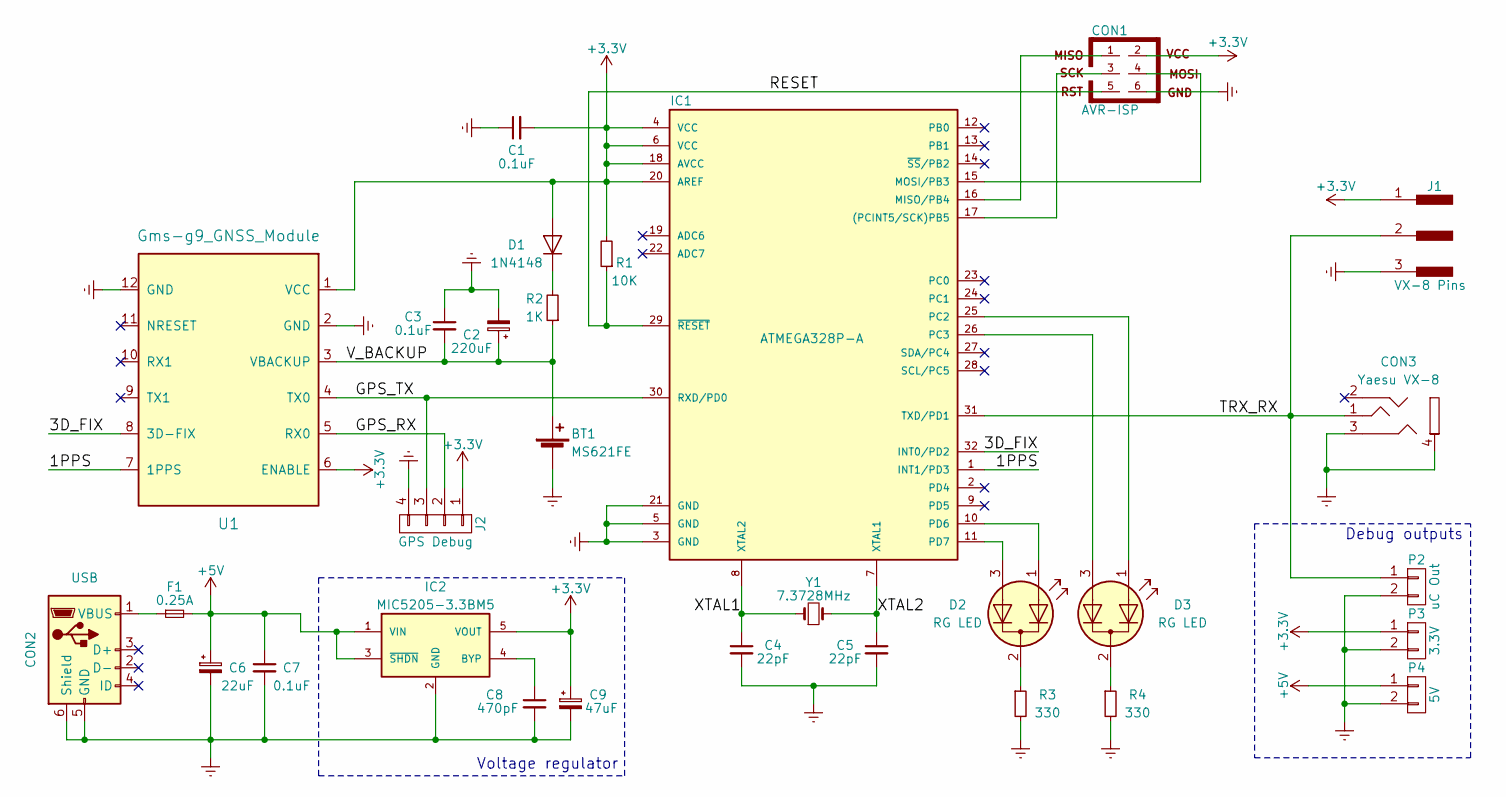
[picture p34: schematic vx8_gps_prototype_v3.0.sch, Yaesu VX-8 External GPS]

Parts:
BT1: MS621FE; Seiko_MS621FE-FL11E_Battery
C1, C3, C7: 0.1uF; C_1206
C2: 220uF; CP_Elec_5x5.3
C4, C5: 22pF; C_1206
C6: 22uF; CP_Elec_4x4.5
C8: 470pF; C_1206
C9: 47uF; CP_Elec_4x4.5
CON1: AVR-ISP; Pin_Header_Straight_2x03_Pitch2.54mm
CON2: USB; USB_Mini-B
CON3: Yaesu VX-8; PJ320D_3.5mm_Jack_Short
D1: 1N4148; D_MiniMELF_Standard
D2, D3: RG LED; LED_D3.0mm-3
F1: 0.25A; Fuse_SMD1206_Wave
IC1: ATMEGA328P-A; TQFP-32_7x7mm_Pitch0.8mm
IC2: MIC5205-3.3BM5; SOT-23-5
J1: VX-8 Pins; Connection_Pads_03
J2: GPS Debug; Pin_Header_Straight_1x04_Pitch2.54mm
P2: uC Out; Pin_Header_Straight_1x02_Pitch2.54mm
P3: 3.3V; Pin_Header_Straight_1x02_Pitch2.54mm
P4: 5V; Pin_Header_Straight_1x02_Pitch2.54mm
R1: 10K; R_1206
R2: 1K; R_1206
R3, R4: 330; R_1206
U1: Gms-g9_GNSS_Module
Y1: 7.3728MHz; Crystal_HC49-4H_Vertical

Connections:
+3V3: C1.2, C9.1, CON1.2, D1.2 (A), IC1.4 (VCC), IC1.6 (VCC), IC1.18 (AVCC), IC1.20 (AREF), IC2.5 (VOUT), J1.1, J2.1, P3.1, R1.2, U1.1 (VCC), U1.6 (ENABLE)
+5V: C6.1, C7.1, F1.2, IC2.1 (VIN), IC2.3 (~SHDN~), P4.1
/1PPS: IC1.1 (INT1/PD3), U1.7 (1PPS)
/3D_FIX: IC1.32 (INT0/PD2), U1.8 (3D-FIX)
/GPS_RX: J2.2, U1.5 (RX0)
/GPS_TX: IC1.30 (RXD/PD0), J2.3, U1.4 (TX0)
/RESET: CON1.5, IC1.29 (~RESET~), R1.1
/TRX_RX: CON3.1 (R), IC1.31 (TXD/PD1), J1.2, P2.1
/V_BACKUP: BT1.1 (+), C2.1, C3.2, R2.1, U1.3 (VBACKUP)
/XTAL1: C4.1, IC1.8 (XTAL2), Y1.1
/XTAL2: C5.1, IC1.7 (XTAL1), Y1.2
GNDREF: BT1.2 (-), C1.1, C2.2, C3.1, C4.2, C5.2, C6.2, C7.2, C8.2, C9.2, CON1.6, CON2.5 (GND), CON2.6 (Shield), CON3.3 (GND), CON3.4 (Mic), IC1.3 (GND), IC1.5 (GND), IC1.21 (GND), IC2.2 (GND), J1.3, J2.4, P2.2, P3.2, P4.2, R3.2, R4.2, U1.2 (GND), U1.12 (GND)
unnamed: C8.1, IC2.4 (BYP)
unnamed: CON1.1, IC1.16 (MISO/PB4)
unnamed: CON1.3, IC1.17 ((PCINT5/SCK)PB5)
unnamed: CON1.4, IC1.15 (MOSI/PB3)
unnamed: CON2.1 (VBUS), F1.1
unnamed: D1.1 (K), R2.2
unnamed: D2.1 (A1), IC1.10 (PD6)
unnamed: D2.2 (K), R3.1
unnamed: D2.3 (A2), IC1.11 (PD7)
unnamed: D3.1 (A1), IC1.25 (PC2)
unnamed: D3.2 (K), R4.1
unnamed: D3.3 (A2), IC1.26 (PC3)

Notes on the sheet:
Debug outputs
Voltage regulator

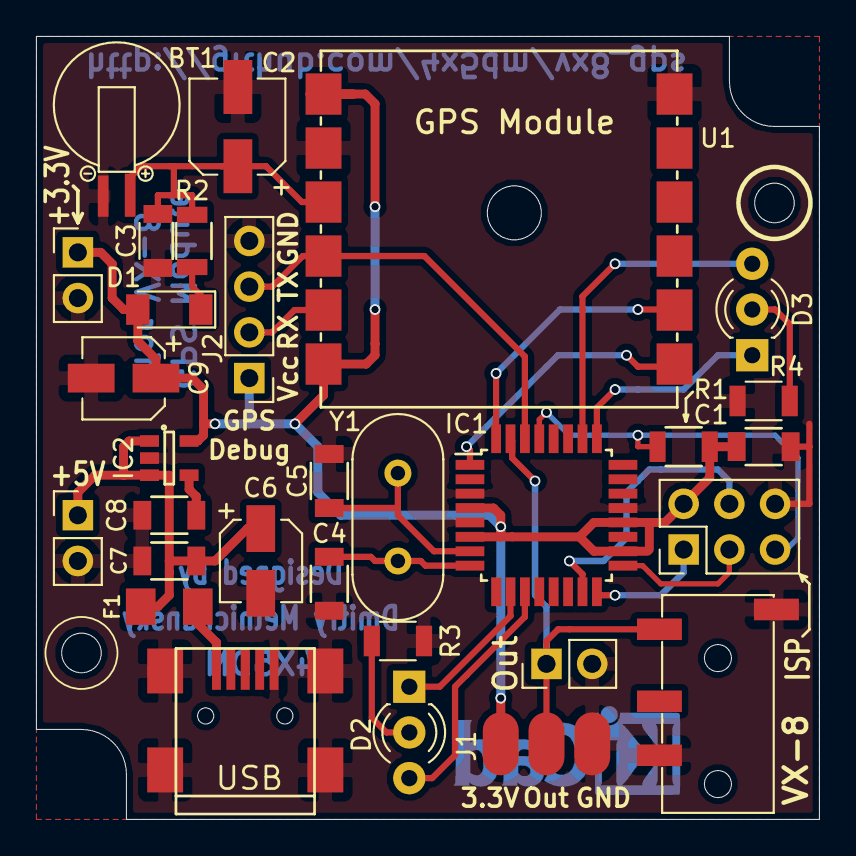
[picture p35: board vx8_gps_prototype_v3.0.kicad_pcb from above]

Board: 2 copper layers, 43.5 x 43.5 mm, 32 parts (0 on the bottom side), 24 nets.

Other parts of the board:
MH1, MH2: M2; MountingHole_2.2mm_M2

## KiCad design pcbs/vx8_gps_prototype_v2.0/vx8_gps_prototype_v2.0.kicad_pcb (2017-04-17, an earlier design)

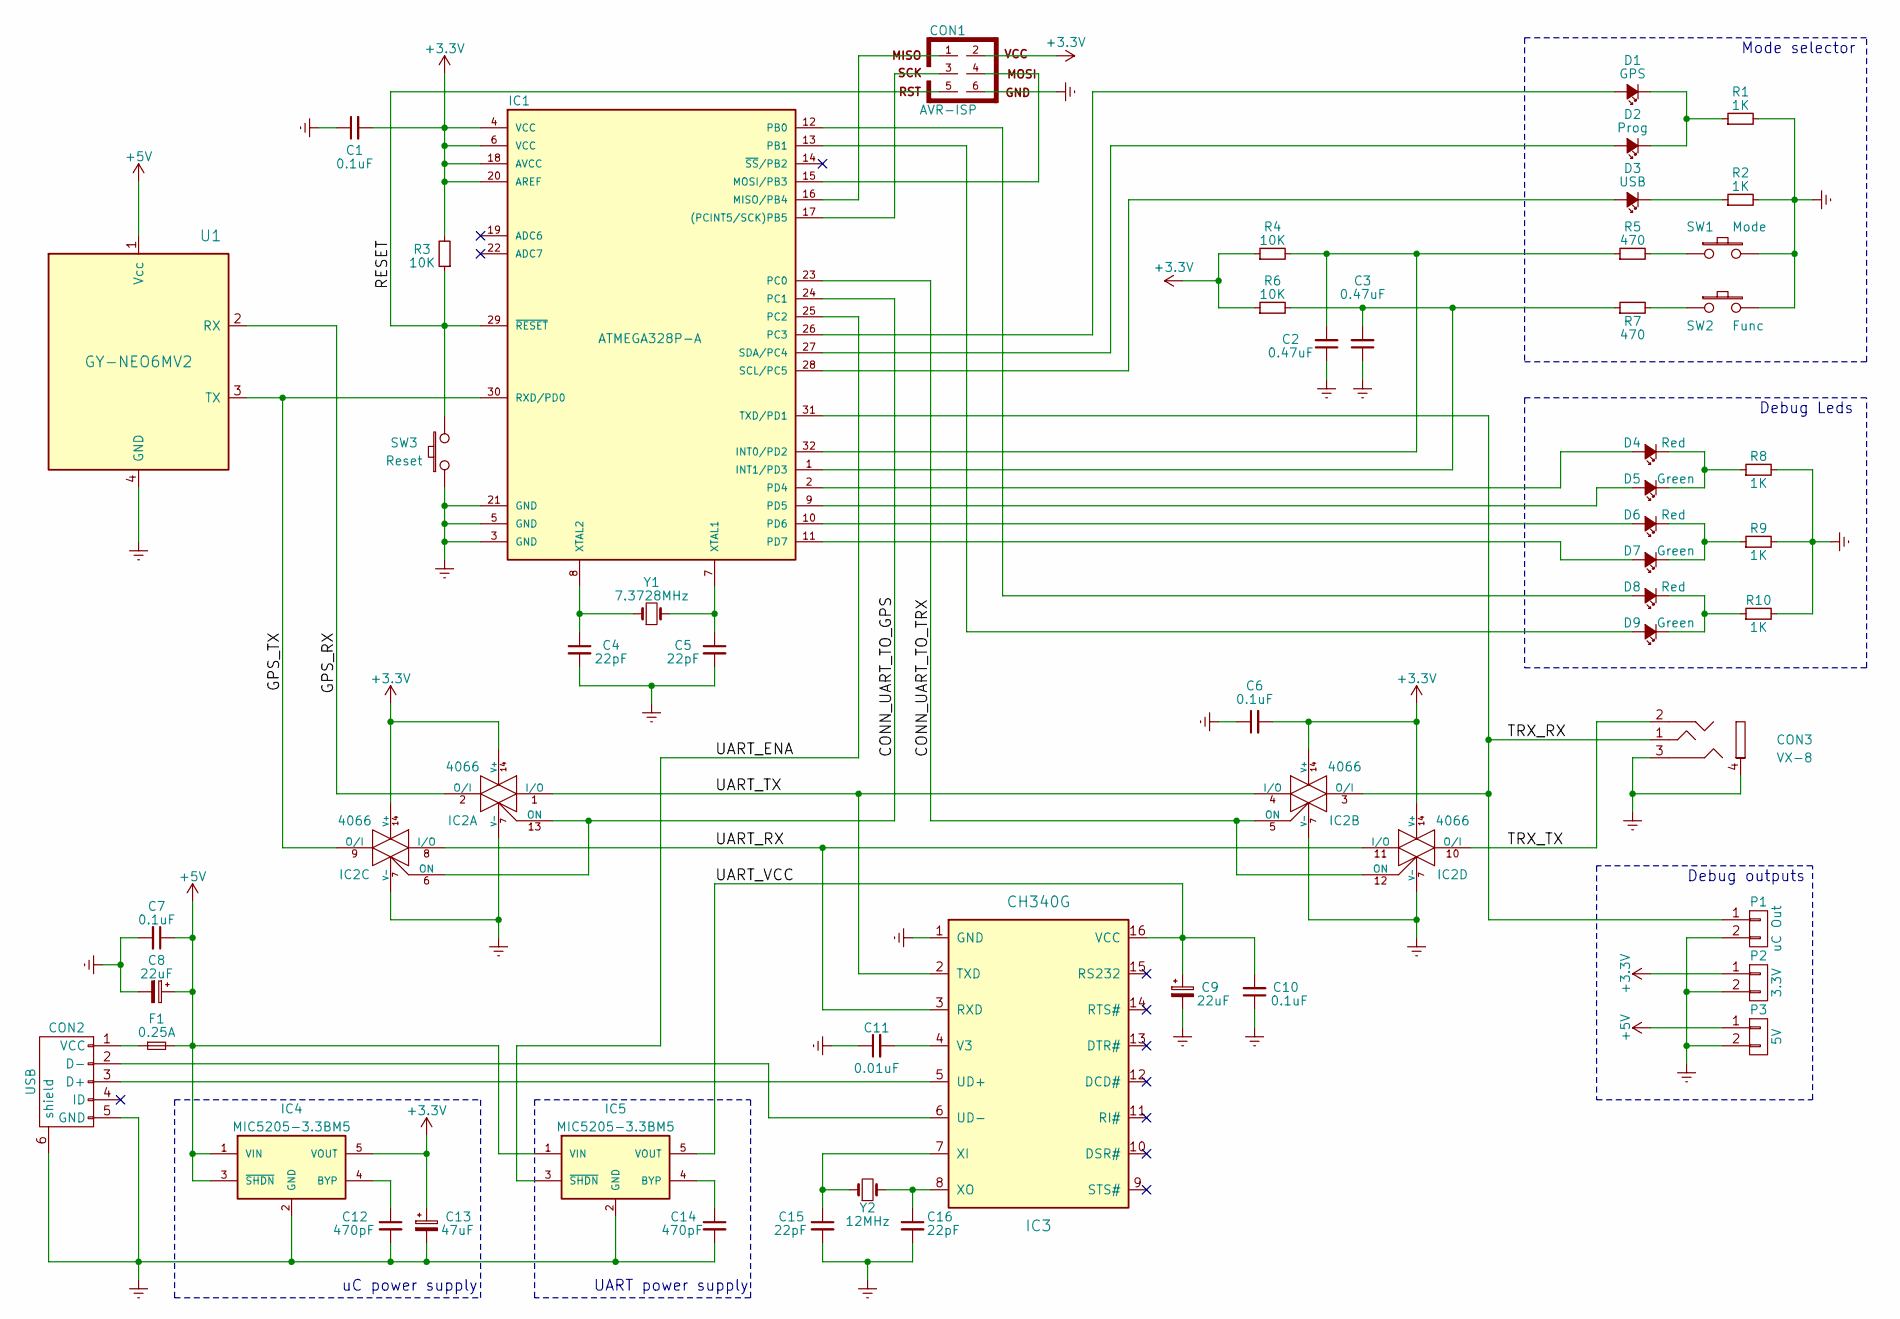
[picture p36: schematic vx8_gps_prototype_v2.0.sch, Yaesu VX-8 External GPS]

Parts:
C1, C6, C7, C10: 0.1uF; C_1206
C2, C3: 0.47uF; C_1206
C4, C5, C15, C16: 22pF; C_1206
C8, C9: 22uF; C_Radial_D5_L6_P2.5
C11: 0.01uF; C_1206
C12, C14: 470pF; C_1206
C13: 47uF; C_Radial_D5_L6_P2.5
CON1: AVR-ISP; Pin_Header_Straight_2x03
CON2: USB; USB_Mini-B
CON3: VX-8; PJ320D_3.5mm_Jack
D1: GPS; LED_1206
D2: Prog; LED_1206
D3: USB; LED_1206
D4, D6, D8: Red; LED_1206
D5, D7, D9: Green; LED_1206
F1: 0.25A; Fuse_SMD1206_Wave
IC1: ATMEGA328P-A; TQFP-32_7x7mm_Pitch0.8mm
IC2: 4066; SOIC-14_3.9x8.7mm_Pitch1.27mm
IC3: CH340G; SOIC-16_3.9x9.9mm_Pitch1.27mm
IC4, IC5: MIC5205-3.3BM5; SOT-23-5
P1: uC Out; Pin_Header_Straight_1x02_Pitch2.54mm
P2: 3.3V; Pin_Header_Straight_1x02_Pitch2.54mm
P3: 5V; Pin_Header_Straight_1x02_Pitch2.54mm
R1, R2, R8, R9, R10: 1K; R_1206
R3, R4, R6: 10K; R_1206
R5, R7: 470; R_1206
SW1: Mode; SW_SPST_PTS645
SW2: Func; SW_SPST_PTS645
SW3: Reset; SW_SPST_B3U-1000P
U1: GY-NEO6MV2; GY-NEO6MV2_GPS
Y1: 7.3728MHz; HC-49V
Y2: 12MHz; Q_49U3HMS

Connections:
+3V3: C1.2, C6.2, C13.1, CON1.2, IC1.4 (VCC), IC1.6 (VCC), IC1.18 (AVCC), IC1.20 (AREF), IC2.14 (V+), IC4.5 (VOUT), P2.1, R3.2, R4.1, R6.1
+5V: C7.1, C8.1, F1.2, IC4.1 (VIN), IC4.3 (~SHDN~), IC5.1 (VIN), P3.1, U1.1 (Vcc)
/CONN_UART_TO_GPS: IC1.24 (PC1), IC2.6 (ON), IC2.13 (ON)
/CONN_UART_TO_TRX: IC1.23 (PC0), IC2.5 (ON), IC2.12 (ON)
/GPS_RX: IC2.2 (O/I), U1.2 (RX)
/GPS_TX: IC1.30 (RXD/PD0), IC2.9 (O/I), U1.3 (TX)
/RESET: CON1.5, IC1.29 (~RESET~), R3.1, SW3.2
/TRX_RX: CON3.1 (R), IC1.31 (TXD/PD1), IC2.3 (O/I), P1.1
/TRX_TX: CON3.2 (L), IC2.10 (O/I)
/UART_ENA: IC1.25 (PC2), IC5.3 (~SHDN~)
/UART_RX: IC2.8 (I/O), IC2.11 (I/O), IC3.3 (RXD)
/UART_TX: IC2.1 (I/O), IC2.4 (I/O), IC3.2 (TXD)
/UART_VCC: C9.1, C10.2, IC3.16 (VCC), IC5.5 (VOUT)
GNDREF: C1.1, C2.1, C3.1, C4.2, C5.2, C6.1, C7.2, C8.2, C9.2, C10.1, C11.1, C12.2, C13.2, C14.2, C15.2, C16.2, CON1.6, CON2.5 (GND), CON2.6 (shield), CON3.3 (GND), CON3.4 (Mic), IC1.3 (GND), IC1.5 (GND), IC1.21 (GND), IC2.7 (V-), IC3.1 (GND), IC4.2 (GND), IC5.2 (GND), P1.2, P2.2, P3.2, R1.2, R2.2, R8.2, R9.2, R10.2, SW1.2, SW2.2, SW3.1, U1.4 (GND)
unnamed: C2.2, IC1.32 (INT0/PD2), R4.2, R5.1
unnamed: C3.2, IC1.1 (INT1/PD3), R6.2, R7.1
unnamed: C4.1, IC1.8 (XTAL2), Y1.1
unnamed: C5.1, IC1.7 (XTAL1), Y1.2
unnamed: C11.2, IC3.4 (V3)
unnamed: C12.1, IC4.4 (BYP)
unnamed: C14.1, IC5.4 (BYP)
unnamed: C15.1, IC3.7 (XI), Y2.1
unnamed: C16.1, IC3.8 (XO), Y2.2
unnamed: CON1.1, IC1.16 (MISO/PB4)
unnamed: CON1.3, IC1.17 ((PCINT5/SCK)PB5)
unnamed: CON1.4, IC1.15 (MOSI/PB3)
unnamed: CON2.1 (VCC), F1.1
unnamed: CON2.2 (D-), IC3.6 (UD-)
unnamed: CON2.3 (D+), IC3.5 (UD+)
unnamed: D1.1 (K), D2.1 (K), R1.1
unnamed: D1.2 (A), IC1.26 (PC3)
unnamed: D2.2 (A), IC1.27 (SDA/PC4)
unnamed: D3.1 (K), R2.1
unnamed: D3.2 (A), IC1.28 (SCL/PC5)
unnamed: D4.1 (K), D5.1 (K), R8.1
unnamed: D4.2 (A), IC1.2 (PD4)
unnamed: D5.2 (A), IC1.9 (PD5)
unnamed: D6.1 (K), D7.1 (K), R9.1
unnamed: D6.2 (A), IC1.10 (PD6)
unnamed: D7.2 (A), IC1.11 (PD7)
unnamed: D8.1 (K), D9.1 (K), R10.1
unnamed: D8.2 (A), IC1.12 (PB0)
unnamed: D9.2 (A), IC1.13 (PB1)
unnamed: R5.2, SW1.1
unnamed: R7.2, SW2.1

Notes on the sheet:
Debug outputs
Debug Leds
Mode selector
uC power supply
UART power supply

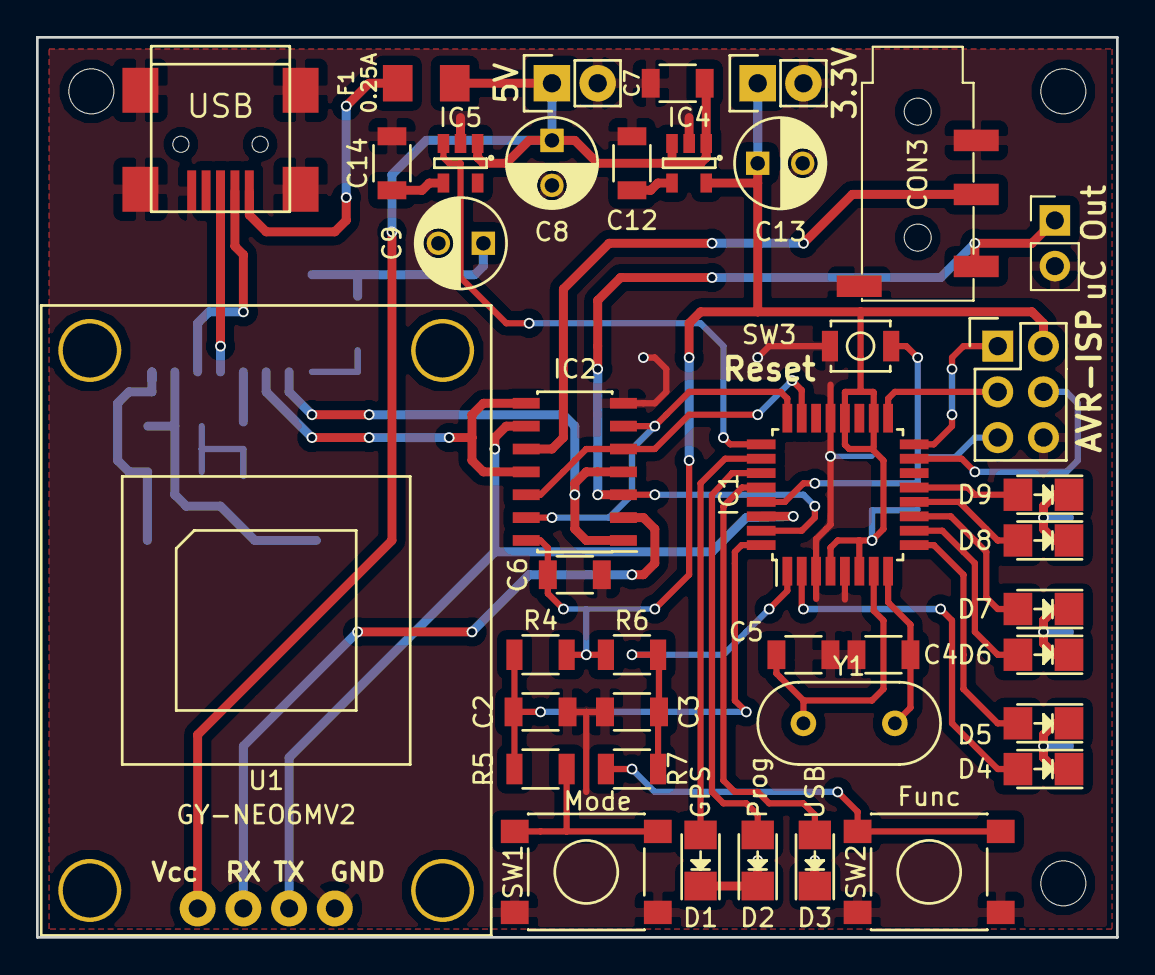
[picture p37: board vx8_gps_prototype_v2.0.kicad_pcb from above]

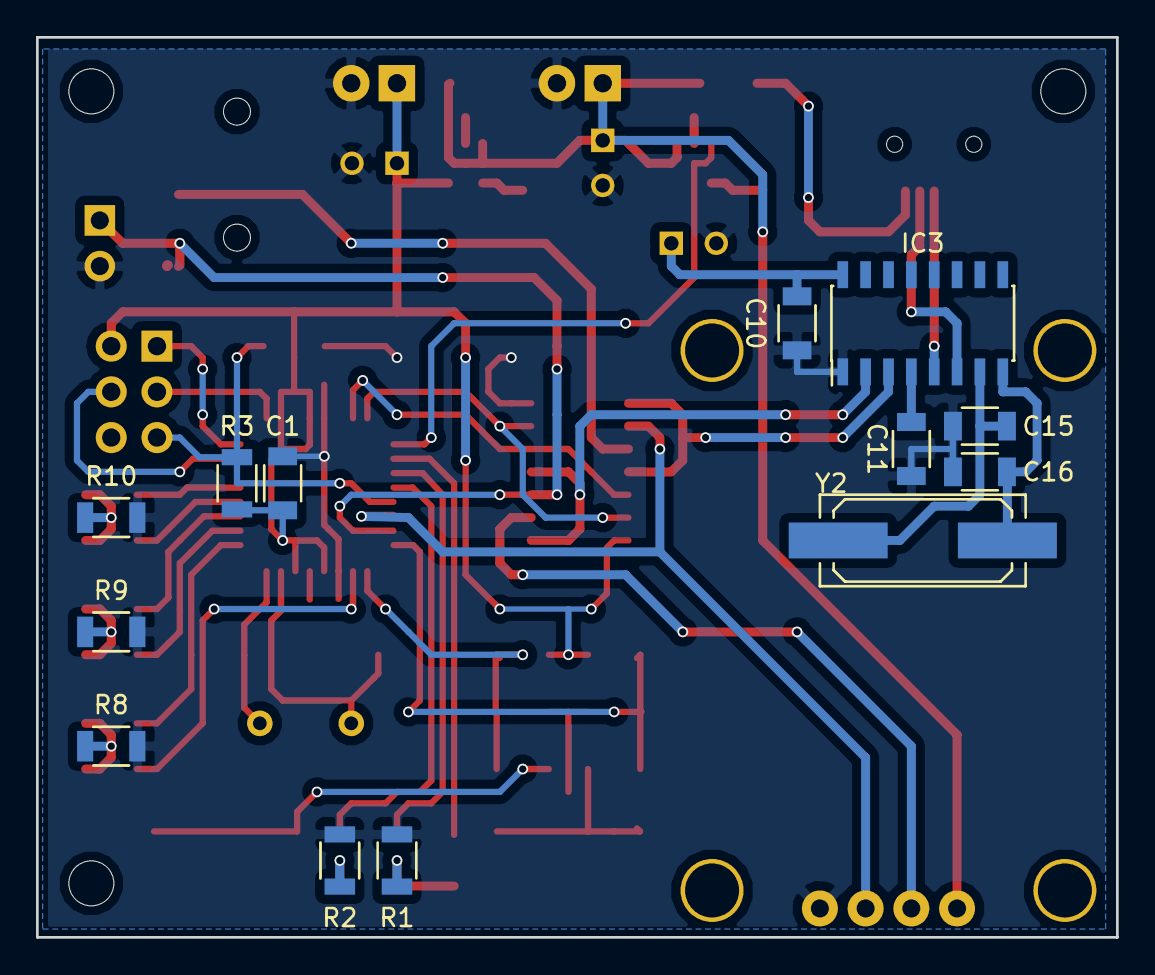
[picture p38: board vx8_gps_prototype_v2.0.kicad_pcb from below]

Board: 2 copper layers, 60.0 x 50.0 mm, 56 parts (13 on the bottom side), 45 nets.

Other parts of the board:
MH1, MH3, MH4: 2.5mm; MountingHole_2.5mm

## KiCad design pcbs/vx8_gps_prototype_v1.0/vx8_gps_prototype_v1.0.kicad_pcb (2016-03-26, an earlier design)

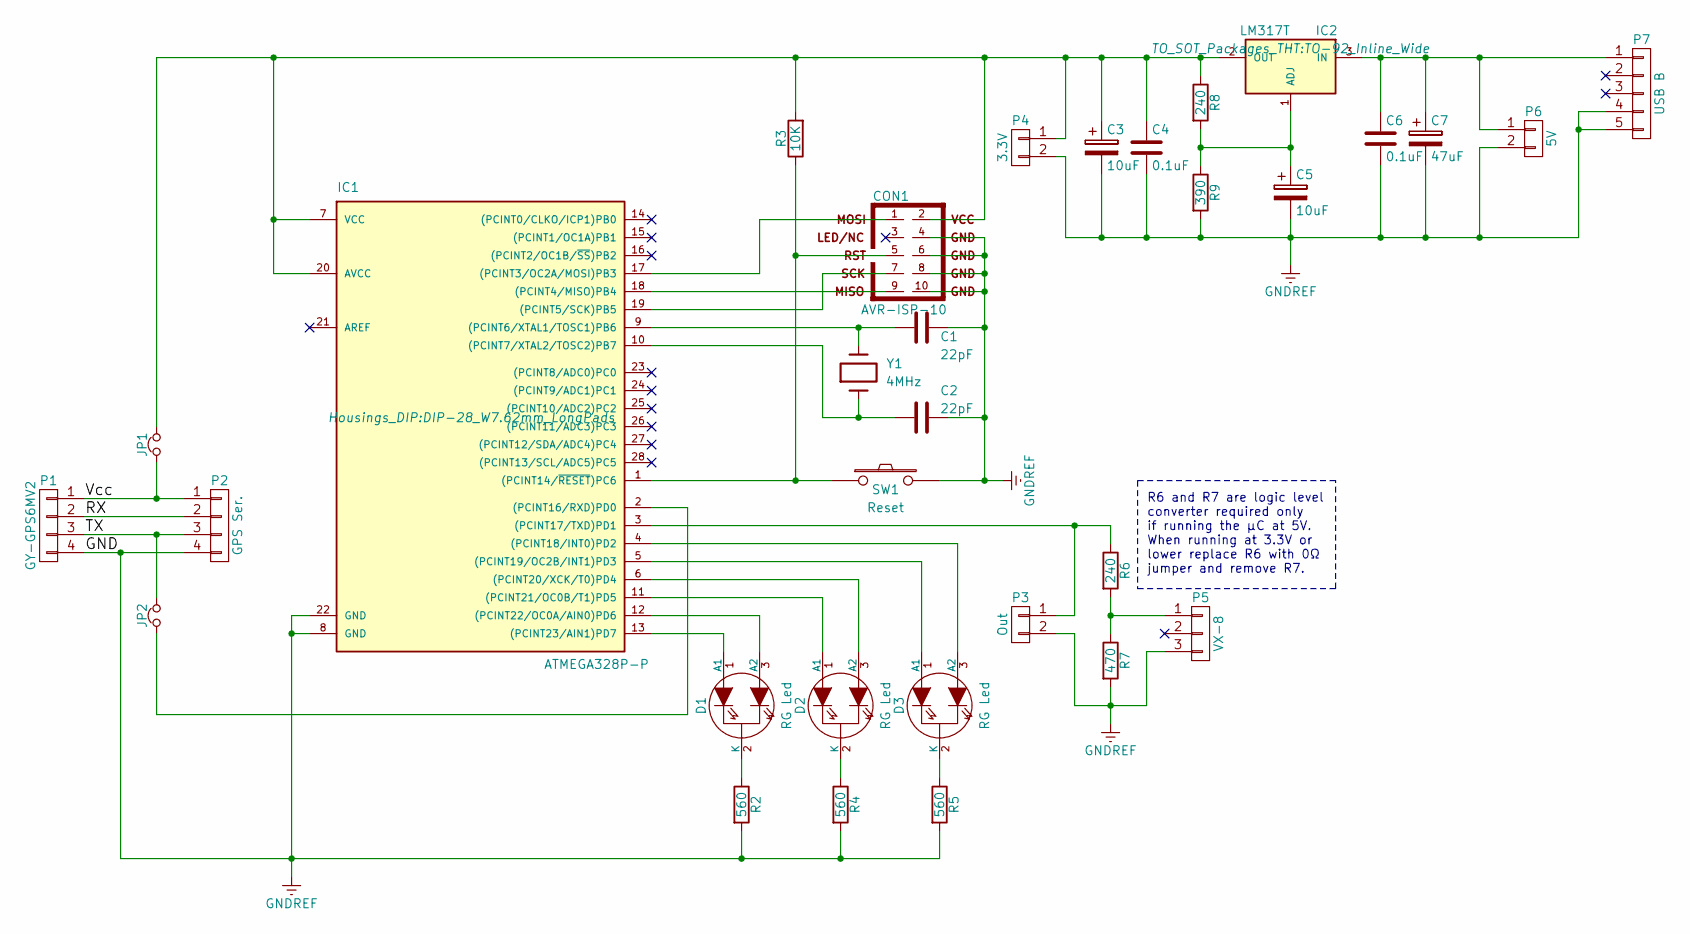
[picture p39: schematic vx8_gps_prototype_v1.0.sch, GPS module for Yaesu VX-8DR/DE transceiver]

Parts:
C1, C2: 22pF; C_1206_HandSoldering
C3, C5: 10uF; C_Radial_D5_L11_P2.5
C4, C6: 0.1uF; C_1206_HandSoldering
C7: 47uF; C_Radial_D5_L11_P2.5
CON1: AVR-ISP-10; Pin_Header_Straight_2x05
D1, D2, D3: RG Led; LED-5MM-3
IC1: ATMEGA328P-P; DIP-28_W7.62mm_LongPads
IC2: LM317T; TO-92_Inline_Wide
JP1: GPS Vcc; Pin_Header_Straight_1x02
JP2: GPS Data; Pin_Header_Straight_1x02
P1: GY-GPS6MV2; Pin_Header_Straight_1x04
P2: GPS Ser.; Pin_Header_Straight_1x04
P3: Out; Pin_Header_Straight_1x02
P4: 3.3V; Pin_Header_Straight_1x02
P5: VX-8; 3.5mm_Jack
P6: 5V; Pin_Header_Straight_1x02
P7: USB B; USB_B
R2, R4, R5: 560; R_1206_HandSoldering
R3: 10K; R_1206_HandSoldering
R6, R8: 240; R_1206_HandSoldering
R7: 470; R_1206_HandSoldering
R9: 390; R_1206_HandSoldering
SW1: Reset; SW_DIP_x1_Slide
Y1: 4MHz; HC-49V

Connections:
/RX: P1.2, P2.2
/TX: JP2.2, P1.3, P2.3
/Vcc: JP1.1, P1.1, P2.1
GNDREF: C1.1, C2.1, C3.2, C4.2, C5.2, C6.2, C7.2, CON1.4, CON1.6, CON1.8, CON1.10, IC1.8 (GND), IC1.22 (GND), P1.4, P2.4, P3.2, P4.2, P5.3, P6.2, P7.4, P7.5, R2.2, R4.2, R5.2, R7.2, R9.2, SW1.2
unnamed: C1.2, IC1.9 ((PCINT6/XTAL1/TOSC1)PB6), Y1.2
unnamed: C2.2, IC1.10 ((PCINT7/XTAL2/TOSC2)PB7), Y1.1
unnamed: C3.1, C4.1, CON1.2, IC1.7 (VCC), IC1.20 (AVCC), IC2.2 (OUT), JP1.2, P4.1, R3.2, R8.1
unnamed: C5.1, IC2.1 (ADJ), R8.2, R9.1
unnamed: C6.1, C7.1, IC2.3 (IN), P6.1, P7.1
unnamed: CON1.1, IC1.17 ((PCINT3/OC2A/MOSI)PB3)
unnamed: CON1.5, IC1.1 ((PCINT14/~RESET~)PC6), R3.1, SW1.1
unnamed: CON1.7, IC1.19 ((PCINT5/SCK)PB5)
unnamed: CON1.9, IC1.18 ((PCINT4/MISO)PB4)
unnamed: D1.1 (A1), IC1.13 ((PCINT23/AIN1)PD7)
unnamed: D1.2 (K), R2.1
unnamed: D1.3 (A2), IC1.12 ((PCINT22/OC0A/AIN0)PD6)
unnamed: D2.1 (A1), IC1.11 ((PCINT21/OC0B/T1)PD5)
unnamed: D2.2 (K), R4.1
unnamed: D2.3 (A2), IC1.6 ((PCINT20/XCK/T0)PD4)
unnamed: D3.1 (A1), IC1.5 ((PCINT19/OC2B/INT1)PD3)
unnamed: D3.2 (K), R5.1
unnamed: D3.3 (A2), IC1.4 ((PCINT18/INT0)PD2)
unnamed: IC1.2 ((PCINT16/RXD)PD0), JP2.1
unnamed: IC1.3 ((PCINT17/TXD)PD1), P3.1, R6.1
unnamed: P5.1, R6.2, R7.1

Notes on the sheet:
R6 and R7 are logic level converter required only if running the μC at 5V. When running at 3.3V or lower replace R6 with 0Ω jumper and remove R7.

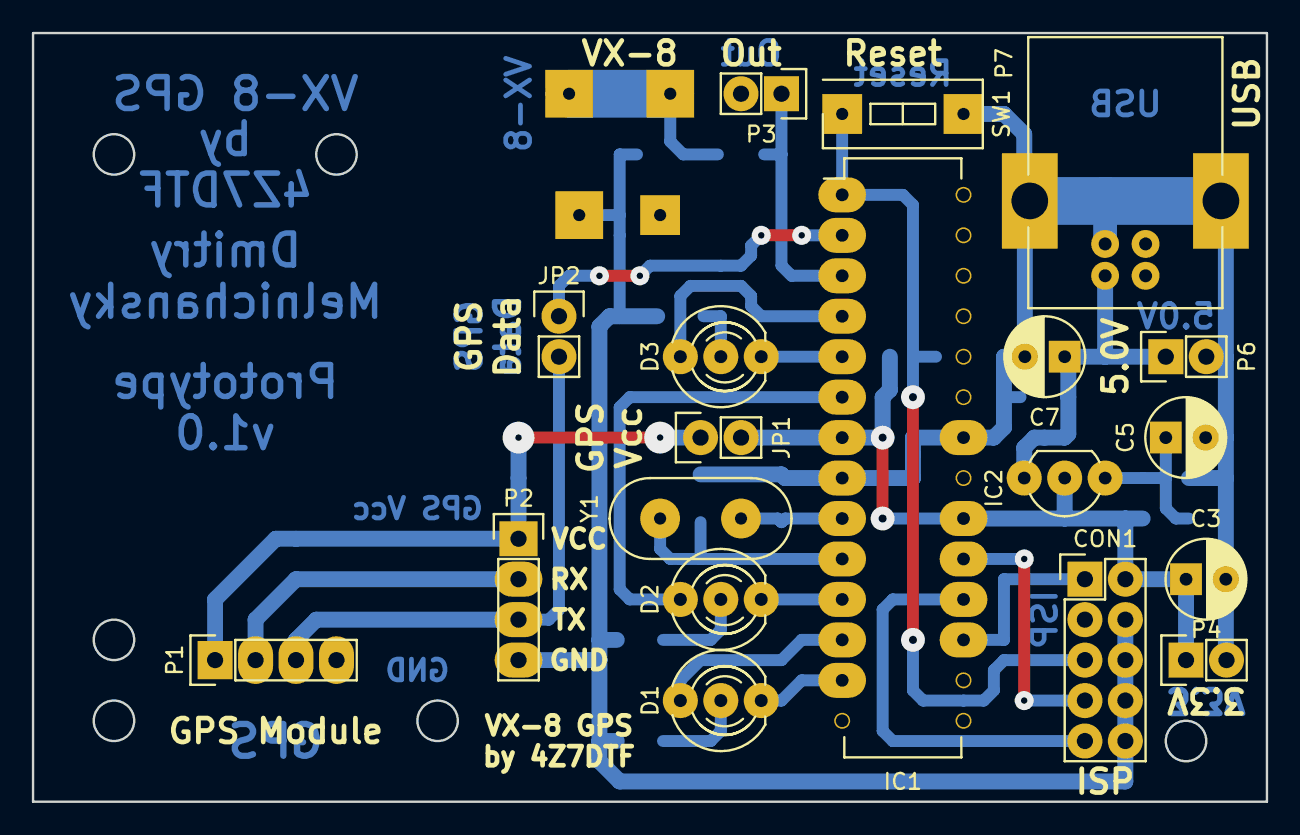
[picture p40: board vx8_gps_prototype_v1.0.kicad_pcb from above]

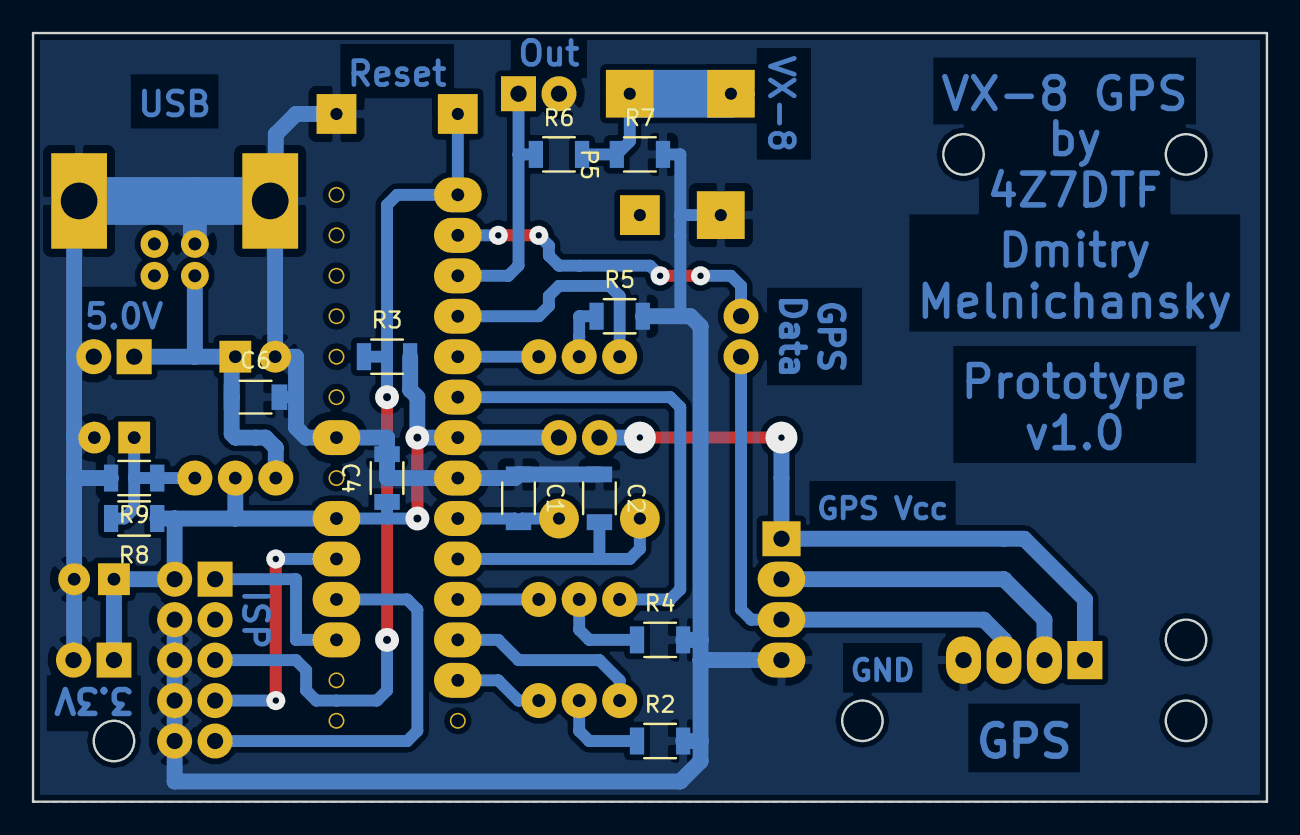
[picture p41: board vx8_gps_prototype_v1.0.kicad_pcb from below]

Board: 2 copper layers, 77.5 x 48.3 mm, 32 parts (13 on the bottom side), 25 nets.

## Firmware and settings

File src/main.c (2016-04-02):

/*
 * vx8_gps.c
 *
 *  Created on: 03 Jan 2016
 *      Author: Dmitry Melnichansky 4Z7DTF
 *  Repository: https://github.com/4z7dtf/vx8_gps
 *
 *  2016-01-03 The program created.
 *  2016-03-28 Stable version which uses TX Complete interrupt. Tested with
 *             Arduino Nano running at 16MHz and with a stand-alone ATmega328P
 *             running at 2MHz.
 *  2016-04-01 USART Buffer Empty interrupt used for TX. TX routines removed
 *             completely from the main loop. Tested with Arduino Nano at 16MHz
 *             and with a stand-alone ATmega328P running at 2MHz.
 */

/*
	No fix:
	$GPGGA,125004.000,,,,,0,00,99.9,,,,,,0000*6D
	$GPRMC,125005.000,V,,,,,,,261215,,,N*4D
	$GPZDA,125004.000,26,12,2015,,*55

	Fix:
	$GPGGA,142615.000,3226.0501,N,03454.8587,E,1,04,8.0,115.5,M,18.2,M,,0000*5B
	$GPRMC,142616.000,A,3226.0485,N,03454.8693,E,6.09,48.89,261215,,,A*57
	$GPZDA,142615.000,26,12,2015,,*52

	NEO-6M vs. Yaesu VX-8
	NEO: $GPGGA,094053.00,3204.41475,N,03445.96499,E,1,09,1.12,28.7,M,17.5,M,,*69
	VX8: $GPGGA,095142.196,4957.5953,N,00811.9616,E,0,00,99.9,00234.7,M,0047.9,M,000.0,0000*42
	VX8: $GPGGA,095142.196,4957.5953 ,N,00811.9616 ,E,0,00,99.9 ,00234.7,M,0047.9,M,000.0,0000*42
	Dif: $GPGGA,094053.00_,3204.4147X,N,03445.9649X,E,1,09,_1.1X,___28.7,M,__17.5,M,___._,____*69

	NEO: $GPRMC,094054.00,A,3204.41446,N,03445.96604,E,3.876,110.45,231215,,,A*62
	VX8: $GPRMC,095142.196,V,4957.5953,N,00811.9616,E,9999.99,999.99,080810,,*2C
	VX8: $GPRMC,095142.196,V,4957.5953 ,N,00811.9616 ,E,9999.99 ,999.99,080810,,  *2C
	Dif: $GPRMC,094054.00_,A,3204.4144X,N,03445.9660X,E,___3.87X,110.45,231215,,XX*62

	NEO: $GPZDA,142615.00,26,12,2015,,*52
	VX8: $GPZDA,095143.196,08,08,2010,,*51
	Dif: $GPZDA,142615.00_,26,12,2015,,*52
 */

#include <avr/io.h>
#include <avr/interrupt.h>
#include "../src/str_func.h"

#define bool uint8_t
#define true 0x01
#define false 0x00

#define USART_BAUDRATE 9600
#define UBRR_VALUE (((F_CPU / (USART_BAUDRATE * 16UL))) - 1)

/* Led output pin deifinitions. */
#define GGA_GREEN 0B10000000 /* GGA sentence invalid */
#define GGA_RED 0B01000000 /* GGA sentence invalid */
#define RMC_GREEN 0B00100000 /* RMC sentence valid */
#define RMC_RED 0B00010000 /* RMC sentence invalid */
#define ALL_OFF 0B00000011 /* All LEDs off */

/* Different sources state that maximum sentence length is 80 characters
 * plus CR and LF. Actual Yaesu FGPS-2 GPS output shows that this standard
 * is ignored and GGA message reaches 86 symbols. That's why the buffer sizes
 * are limited to 90 characters instead of 82.
 */
#define BUFFER_SIZE 90
#define COMMA ','
#define DOLLAR '$'
#define ASTERISK '*'
#define CR 0x0D
#define LF 0x0A
#define NULL 0x00 /* No data and string termination in RX and TX buffers. */

/* TX and RX buffers structure */
struct buffer
{
	char buffer[BUFFER_SIZE];
	uint8_t pos;
};

/* Function prototypes. */
bool process_field(void);
void reset_buffer(volatile struct buffer *);
void usart_init(void);

/* RX variables */
enum rx_states
{
	READY, /* Default state, ready to receive. Changes if $ is received. */
	RX_TYPE_DETECT, /* Detecting message type (RMC, GGA etc.) Changes if comma is received. */
	RX_MESSAGE, /* Receiving the message between the $ and * delimiters. */
	RX_CHECKSUM, /* Receiving the checksum. Changes if \r\n  is received. */
	START_TX, /* Sends the message to TX when tx_has_data flag is cleared. */
	RESET, /* Resets the RX to READY state. */
};
uint8_t state; /* Current system state. */

enum nmea_commands
{
	NONE, GGA, RMC, ZDA
};
uint8_t rx_command; /* NMEA command being received. */
uint8_t rx_field_num; /* Current field of NMEA command. */
uint8_t rx_field_size; /* Current field size. */

struct buffer rx_buffer; /* Buffer for the received message. */
volatile uint8_t rx_byte; /* Received byte. */
uint8_t tbp_byte; /* Byte to process. */
uint8_t calc_checksum; /* Calculated checksum of the received message. Calculated on the fly. */
uint8_t rx_checksum; /* Checksum of the received NMEA sentence. */

/* Lookup table for converting numerical values to hexadecimal digits. */
char hex_chars[16] = { '0', '1', '2', '3', '4', '5', '6', '7', '8', '9', 'A', 'B', 'C', 'D', 'E', 'F' };

/* TX variables */
struct buffer tx_buffer;
volatile bool tx_has_data; /* TX has a message to send. Set to false when tx_buffer is empty. */

int main(void)
{
	/* Setup */
	DDRD = DDRD | 0B11111100;
	PORTD &= ALL_OFF;
	usart_init();
	reset_buffer(&tx_buffer);
	rx_byte = NULL;
	state = RESET;
	sei();

	/* Main loop */
	while (1)
	{
		/* RX routine */
		if(rx_byte)
		{
			tbp_byte = rx_byte;
			rx_byte = NULL;
		}

		switch (state)
		{
		case READY:
			/* READY: The system is ready to receive and remains is this state
			 * until $ character is received.
			 */
			if (tbp_byte == DOLLAR)
			{
				rx_buffer.buffer[rx_buffer.pos] = tbp_byte;
				rx_buffer.pos++;
				state = RX_TYPE_DETECT;
			}
			tbp_byte = NULL;
			break;

		case RX_TYPE_DETECT:
			/* RX_TYPE_DETECT: The system receives the first field of NMEA
			 * sentence and when comma is received tries to detect sentence
			 * type (GGA, RMC or ZDA). If supported sentence type is detected,
			 * the state changes to RX_MESSAGE. Otherwise the system is reset
			 * and returns to READY state.
			 */
			if (tbp_byte)
			{
				rx_buffer.buffer[rx_buffer.pos] = tbp_byte;
				rx_buffer.pos++;
				calc_checksum ^= tbp_byte;

				if(tbp_byte == COMMA)
				{
					if (rx_buffer.buffer[3] == 'G' && rx_buffer.buffer[4] == 'G' && rx_buffer.buffer[5] == 'A')
					{
						rx_command = GGA;
					}
					else if (rx_buffer.buffer[3] == 'R' && rx_buffer.buffer[4] == 'M' && rx_buffer.buffer[5] == 'C')
					{
						rx_command = RMC;
					}
					else if (rx_buffer.buffer[3] == 'Z' && rx_buffer.buffer[4] == 'D' && rx_buffer.buffer[5] == 'A')
					{
						rx_command = ZDA;
					}

					if (rx_command != NONE)
					{
						rx_field_num++;
						state = RX_MESSAGE;
					}
					else
					{
						state = RESET;
					}
				}
				tbp_byte = NULL;
			}
			break;

		case RX_MESSAGE:
			/* RX_MESSAGE: The system receives the message between $ and *
			 * delimiters. NMEA sentence checksum is calculated on the fly.
			 * Comma character marks end of field. Each time it is
			 * received, the field is verified and changed to VX-8 specific
			 * format if required. Changing the fields on the fly results
			 * in getting a new VX-8 compatible message at the end of reception.
			 * NMEA sentences with empty time fields are discarded. The system
			 * stops receiving current sentence and returns to READY. This is
			 * done to prevent sending false time to VX-8. Other empty fields
			 * are filled with default values, in most cases zeros. That's why
			 * VX-8 shows zeros in coordinate fields when GPS fix isn't acquired
			 * or is lost.
			 * When * character is received the state changes to RX_CHECKSUM.
			 */
			if (tbp_byte)
			{
				/* If received character is $ or the buffer is overflown,
				 * reset and return to READY state.
				 */
				if (tbp_byte == DOLLAR || rx_buffer.pos >= BUFFER_SIZE)
				{
					state = RESET;
					break;
				}

				/* Comma and marks end of field, asterisk marks end of message
				 * which is also end of the last field.
				 */
				if (tbp_byte == COMMA || tbp_byte == ASTERISK)
				{
					bool field_valid = process_field();
					if (!field_valid)
					{
						state = RESET;
						break;
					}
					rx_field_num++;
					rx_field_size = 0;
				}
				else
				{
					rx_field_size++;
				}

				rx_buffer.buffer[rx_buffer.pos] = tbp_byte;
				rx_buffer.pos++;

				/* If end of message, change state to RX_CHECKSUM
				 * without affecting the calculated checksum.
				 */
				if (tbp_byte == ASTERISK)
				{
					state = RX_CHECKSUM;
				}
				else
				{
					calc_checksum ^= tbp_byte;
				}

				tbp_byte = NULL;
			}
			break;
		case RX_CHECKSUM:
			/* RX_CHECKSUM: The system receives the checksum (first two bytes
			 * after *). After CR (\r) character is received, the system
			 * compares it to the calculated value. If two values match,
			 * a new checksum is calculated and added to the message.
			 * Upon receiving the LF (\n) character which marks end of sentence
			 * system state changes to START_TX.
			 */
			if (tbp_byte)
			{
				/* If received character is $ or * or the buffer is overflown,
				 * reset and return to READY state.
				 */
				if (tbp_byte == DOLLAR || tbp_byte == ASTERISK || rx_buffer.pos >= BUFFER_SIZE)
				{
					state = RESET;
					break;
				}
				/* CR (\r) is received after the last character of checksum. */
				else if (tbp_byte == CR)
				{
					/* If match, calculate a new one, else reset. */
					if (rx_checksum == calc_checksum)
					{
						uint8_t checksum = 0x00;
						for (uint8_t i = 1; i < (rx_buffer.pos - 1); i++)
						{
							checksum ^= rx_buffer.buffer[i];
						}
						rx_buffer.buffer[rx_buffer.pos] = hex_chars[(checksum & 0xF0) >> 4];
						rx_buffer.pos++;
						rx_buffer.buffer[rx_buffer.pos] = hex_chars[checksum & 0x0F];
						rx_buffer.pos++;
						rx_buffer.buffer[rx_buffer.pos] = tbp_byte;
						rx_buffer.pos++;
					}
					else
					{
						state = RESET;
					}
				}
				/* LF (\n) is the last symbol of NMEA message. */
				else if (tbp_byte == LF)
				{
					rx_buffer.buffer[rx_buffer.pos] = tbp_byte;
					rx_buffer.pos++;
					state = START_TX;
				}
				/* Characters 0-9 and A-F are converted to numbers and added to checksum.
				 * Digit symbols have values 0x30-0x39. Capital letters start from 0x41.
				 * If the received byte is a letter (val. 0x4X) we subtract 0x07
				 * to convert the value to 0x3A-0x3F. Bitwise AND with 0x0F converts
				 * the value to 0x00-0x0F.
				 * Previous value of the received checksum is rotated 4 bits left. If the first
				 * byte of the checksum was received, the value is 0x00 and isn't affected.
				 * If the second byte is received, the value 0x0X becomes 0xX0 leaving a
				 * place for the second digit.
				 */
				else
				{
					uint8_t val = tbp_byte;
					if (val & 0x40)
						val -= 0x07;
					val &= 0x0F;
					rx_checksum <<= 4;
					rx_checksum |= val;
				}

				tbp_byte = NULL;
			}
			break;

		case START_TX:
			/* START_TX: The received and reformatted message is transferred
			 * to TX buffer. If the buffer isn't empty, the system remains in
			 * this state until the previous message is sent. After sending
			 * the message to TX system moves to READY state.
			 */
			if (!tx_has_data)
			{
				reset_buffer(&tx_buffer);
				/* Copy contents of RX buffer to TX buffer. */
				for (uint8_t i = 0; rx_buffer.buffer[i]; i++)
				{
					tx_buffer.buffer[i] = rx_buffer.buffer[i];
				}
				tx_has_data = true;
				UDR0 = tx_buffer.buffer[0];
				UCSR0B |= (1 << UDRIE0); /* Enable buffer empty interrupt */
				state = RESET;
				PORTD &= ALL_OFF; /* Turn all the LEDs off. */
			}
			break;

		case RESET:
			/* RESET: resets the RX to READY state.
			 */
			reset_buffer(&rx_buffer);
			calc_checksum = 0x00;
			rx_checksum = 0x00;
			rx_command = NONE;
			rx_field_num = 0;
			rx_field_size = 0;
			tbp_byte = NULL;
			state = READY;
			break;
		}
		/* End RX routine */
	}

	return (0);
}

/*
 * Function: process_field
 * -----------------------
 *   Determines message type from the 0th field and changes the length
 *   of last received field if required.
 *
 *   returns:	True if the field was valid, false if the message has to be discarded
 *   			due to current field's value.
 */
bool process_field(void)
{
	bool res = true;

	switch (rx_command)
	{
	case GGA:
		/* NEO-6M vs. Yaesu VX-8
		 * NEO:    $GPGGA,094053.00,3204.41475,N,03445.96499,E,1,09,1.12,28.7,M,17.5,M,,*69
		 * VX8:    $GPGGA,095142.196,4957.5953,N,00811.9616,E,0,00,99.9,00234.7,M,0047.9,M,000.0,0000*42
		 * Dif:    $GPGGA,094053.00_,3204.4147X,N,03445.9649X,E,1,09,_1.1X,___28.7,M,__17.5,M,___._,____*69
		 * Fields:      0          1          2 3           4 5 6  7     8       9 A      B C     D    E
		 */
		switch (rx_field_num)
		{
		case 0x00:
			/* Added for switch() optimization purposes. */
			break;
		case 0x01:
			/* If time field is empty all the message is discarded. */
			if (rx_field_size == 0)
			{
				PORTD |= GGA_RED; /* Turn the red LED on. */
				res = false;
				break;
			}
			/* Time field is fixed to 10 characters: hhmmss.sss */
			fix_decimal_field_len(&rx_buffer.buffer[rx_buffer.pos - rx_field_size], rx_field_size, 6, 3);
			rx_buffer.pos -= rx_field_size;
			rx_buffer.pos += 10;
			break;
		case 0x02:
			if (rx_field_size == 0)
				PORTD |= GGA_RED; /* Red LED on. */
			else
				PORTD |= GGA_GREEN; /* Green LED on. */
			/* Latitude field is fixed to 9 characters: ddmm.ssss */
			fix_decimal_field_len(&rx_buffer.buffer[rx_buffer.pos - rx_field_size], rx_field_size, 4, 4);
			rx_buffer.pos -= rx_field_size;
			rx_buffer.pos += 9;
			break;
		case 0x03:
			/* Latitude N/S field is set to N if empty. */
			if (rx_field_size == 0)
			{
				rx_buffer.buffer[rx_buffer.pos] = 'N';
				rx_buffer.pos++;
			}
			break;
		case 0x04:
			/* Longitude field is fixed to 10 characters: dddmm.ssss */
			fix_decimal_field_len(&rx_buffer.buffer[rx_buffer.pos - rx_field_size], rx_field_size, 5, 4);
			rx_buffer.pos -= rx_field_size;
			rx_buffer.pos += 10;
			break;
		case 0x05:
			/* Longitude E/W field is set to E if empty. */
			if (rx_field_size == 0)
			{
				rx_buffer.buffer[rx_buffer.pos] = 'E';
				rx_buffer.pos++;
			}
			break;
		case 0x06:
			/* Field 6 doesn't require modification. */
			break;
		case 0x07:
			/* Number of satellites is integer fixed to 2 characters. */
			fix_int_field_len(&rx_buffer.buffer[rx_buffer.pos - rx_field_size], rx_field_size, 2);
			rx_buffer.pos -= rx_field_size;
			rx_buffer.pos += 2;
			break;
		case 0x08:
			/* Horizontal dilution of position field is fixed to 4 characters: xx.x.
			 * In the case of NEO-U-6 it means that one character after the decimal point
			 * will be truncated. */
			fix_decimal_field_len(&rx_buffer.buffer[rx_buffer.pos - rx_field_size], rx_field_size, 2, 1);
			rx_buffer.pos -= rx_field_size;
			rx_buffer.pos += 4;
			break;
		case 0x09:
			/* Altitude above mean sea is fixed to 7 characters: aaaaa.a */
			fix_decimal_field_len(&rx_buffer.buffer[rx_buffer.pos - rx_field_size], rx_field_size, 5, 1);
			rx_buffer.pos -= rx_field_size;
			rx_buffer.pos += 7;
			break;
		case 0x0A:
			/* Altitude units are set to M (meters) if this field is empty. */
			if (rx_field_size == 0)
			{
				rx_buffer.buffer[rx_buffer.pos] = 'M';
				rx_buffer.pos++;
			}
			break;
		case 0x0B:
			/* Height of geoid field is fixed to 6 characters: ddd.mm */
			fix_decimal_field_len(&rx_buffer.buffer[rx_buffer.pos - rx_field_size], rx_field_size, 4, 1);
			rx_buffer.pos -= rx_field_size;
			rx_buffer.pos += 6;
			break;
		case 0x0C:
			/* Altitude units are set to M (meters) if this field is empty. */
			if (rx_field_size == 0)
			{
				rx_buffer.buffer[rx_buffer.pos] = 'M';
				rx_buffer.pos++;
			}
			break;
		case 0x0D:
			/* Time since last DGPS update field is fixed to 5 characters: ddd.m */
			fix_decimal_field_len(&rx_buffer.buffer[rx_buffer.pos - rx_field_size], rx_field_size, 3, 1);
			rx_buffer.pos -= rx_field_size;
			rx_buffer.pos += 5;
			break;
		case 0x0E:
			/* DGPS station ID number is integer fixed to 4 characters. */
			fix_int_field_len(&rx_buffer.buffer[rx_buffer.pos - rx_field_size], rx_field_size, 4);
			rx_buffer.pos -= rx_field_size;
			rx_buffer.pos += 4;
			break;
		}
		break;
		/* End case GGA */

	case RMC:
		/* NEO-6M vs. Yaesu VX-8
		 * NEO:    $GPRMC,094054.00,A,3204.41446,N,03445.96604,E,3.876,110.45,231215,,,A*62
		 * VX8:    $GPRMC,095142.196,V,4957.5953,N,00811.9616,E,9999.99,999.99,080810,,*2C
		 * Dif:    $GPRMC,094054.00_,A,3204.4144X,N,03445.9660X,E,___3.87X,110.45,231215,,XX*62
		 * Fields:      0          1 2          3 4           5 6        7      8      9
		 */
		switch (rx_field_num)
		{
		case 0x00:
			/* Added for switch() optimization purposes. */
			break;
		case 0x01:
			/* If time field is empty all the message is discarded. */
			if (rx_field_size == 0)
			{
				PORTD |= RMC_RED; /* Turn the red LED on. */
				res = false;
				break;
			}
			/* Time field is fixed to 10 characters: hhmmss.sss */
			fix_decimal_field_len(&rx_buffer.buffer[rx_buffer.pos - rx_field_size], rx_field_size, 6, 3);
			rx_buffer.pos -= rx_field_size;
			rx_buffer.pos += 10;
			break;
		case 0x02:
			break;
		case 0x03:
			if (rx_field_size == 0)
				PORTD |= RMC_RED; /* Red LED on. */
			else
				PORTD |= RMC_GREEN; /* Green LED on. */
			/* Latitude field is fixed to 9 characters: ddmm.ssss */
			fix_decimal_field_len(&rx_buffer.buffer[rx_buffer.pos - rx_field_size], rx_field_size, 4, 4);
			rx_buffer.pos -= rx_field_size;
			rx_buffer.pos += 9;
			break;
		case 0x04:
			/* Latitude N/S field is set to N if empty. */
			if (rx_field_size == 0)
			{
				rx_buffer.buffer[rx_buffer.pos] = 'N';
				rx_buffer.pos++;
			}
			break;
		case 0x05:
			/* Longitude field is fixed to 10 characters: dddmm.ssss */
			fix_decimal_field_len(&rx_buffer.buffer[rx_buffer.pos - rx_field_size], rx_field_size, 5, 4);
			rx_buffer.pos -= rx_field_size;
			rx_buffer.pos += 10;
			break;
		case 0x06:
			/* Longitude E/W field is set to E if empty. */
			if (rx_field_size == 0)
			{
				rx_buffer.buffer[rx_buffer.pos] = 'E';
				rx_buffer.pos++;
			}
			break;
		case 0x07:
			/* Speed field is fixed to 7 characters: ssss.ss */
			fix_decimal_field_len(&rx_buffer.buffer[rx_buffer.pos - rx_field_size], rx_field_size, 4, 2);
			rx_buffer.pos -= rx_field_size;
			rx_buffer.pos += 7;
			break;
		case 0x08:
			/* Track angle field is fixed to 6 characters: ddd.mm */
			fix_decimal_field_len(&rx_buffer.buffer[rx_buffer.pos - rx_field_size], rx_field_size, 3, 2);
			rx_buffer.pos -= rx_field_size;
			rx_buffer.pos += 6;
			break;
		}
		break;
		/* End case RMC */

	case ZDA:
		/* NEO-6M vs. Yaesu VX-8
		 * NEO:    $GPZDA,142615.00,26,12,2015,,*52
		 * VX8:    $GPZDA,095143.196,08,08,2010,,*51
		 * Dif:    $GPZDA,142615.00_,26,12,2015,,*52
		 * Fields:      0          1  2  3    4
		 */
		if (rx_field_num == 1)
		{
			/* If time field is empty all the message is discarded. */
			if (rx_field_size == 0)
			{
				res = false;
				break;
			}
			/* Time field is fixed to 10 characters: hhmmss.sss */
			fix_decimal_field_len(&rx_buffer.buffer[rx_buffer.pos - rx_field_size], rx_field_size, 6, 3);
			rx_buffer.pos -= rx_field_size;
			rx_buffer.pos += 10;
		}
		break;
	}
	return res;
}

/*
 * Function: reset_buffer
 * ------------------
 *   Resets given buffer to empty state.
 *
 *   returns:	none
 */
void reset_buffer(volatile struct buffer *buf)
{
	for (uint8_t i = 0; i < BUFFER_SIZE; i++)
	{
		buf->buffer[i] = NULL;
	}
	buf->pos = 0;
}

/* UART routines */
/*
 * Function: usart_init
 * --------------------
 *   Initializes UART, enables TX, RX and interrupts.
 *
 *   returns:	none
 */
void usart_init(void)
{
	/* Set baud rate */
	UBRR0H = (uint8_t) (UBRR_VALUE >> 8);
	UBRR0L = (uint8_t) UBRR_VALUE;
	/* Set frame format to 8 data bits, no parity, 1 stop bit */
	UCSR0C |= (1 << UCSZ01) | (1 << UCSZ00);
	/* Enable reception and transmission */
	UCSR0B |= (1 << RXEN0) | (1 << TXEN0);
	/* Enable RX Complete interrupt */
	UCSR0B |= (1 << RXCIE0);
}

/*
 * Function: ISR(USART_RX_vect)
 * ----------------------------
 *   RX Complete interrupt service routine.
 *
 *   returns:	none
 */
ISR(USART_RX_vect)
{
	rx_byte = UDR0;
}

/*
 * Function: ISR(USART_UDRE_vect)
 * ------------------------------
 *   UART Data Register Empty service routine. Sends next byte to buffer
 *   if end of sentence (null terminator) isn't reached. Otherwise clears
 *   tx_has_data flag and disables UART Data Register Empty interrupt.
 *
 *   returns:	none
 */
ISR(USART_UDRE_vect)
{
	tx_buffer.pos++;
	if (tx_buffer.buffer[tx_buffer.pos] != NULL)
	{
		UDR0 = tx_buffer.buffer[tx_buffer.pos];
	}
	else
	{
		UCSR0B &= ~(1 << UDRIE0); /* Disable UDR0 empty interrupt */
		tx_has_data = false;
	}
}

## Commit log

2016-01-10 Binary file for uploading to Arduino.
2016-01-11 Led pins.
2016-01-16 APRS flower.
2016-01-16 Arduino version.
2016-03-20 Arduino code. Tested with Arduino Nano 16MHz on 20 March 2016.
2016-03-25 Led output pin deifinitions.
2016-03-26 Updated Arduino code and hex file.
2016-03-26 Prototype v1.0: KiCAD files.
    [vx8_gps_prototype_v1.0.kicad_pcb, vx8_gps_prototype_v1.0.sch]
2016-03-26 Prototype v1.0: description & photos.
2016-03-28 1. #define directives for constants. 2. Changed str_len() function in str_func.c. 3. Arduino code uses TX complete interrupt instead of UDR0 empty interrupt.
2016-04-01 1. USART Buffer Empty interrupt used for TX. 2. TX routines removed completely from the main loop. All the transmission is processed in the interrupt service routine. 3. Tested with Arduino Nano at 1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
2016-04-02 1. TX and RX buffers changed to struct. 2. reset_rx() replaced with RESET state.
    [main.c]
2016-08-20 GY-NEO6MV2 module outline drawing.
    [GY-NEO6MV2.dxf]
2017-04-17 Prototype v2.0.
    [vx8_gps_prototype_v2.0.kicad_pcb, vx8_gps_prototype_v2.0.sch]
2017-04-17 Prototype v3.0.
    [vx8_gps_prototype_v3.0-B.Cu.gbl, vx8_gps_prototype_v3.0-B.Mask.gbs, vx8_gps_prototype_v3.0-B.SilkS.gbo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]
2020-04-15 Added description about new PCB versions.
